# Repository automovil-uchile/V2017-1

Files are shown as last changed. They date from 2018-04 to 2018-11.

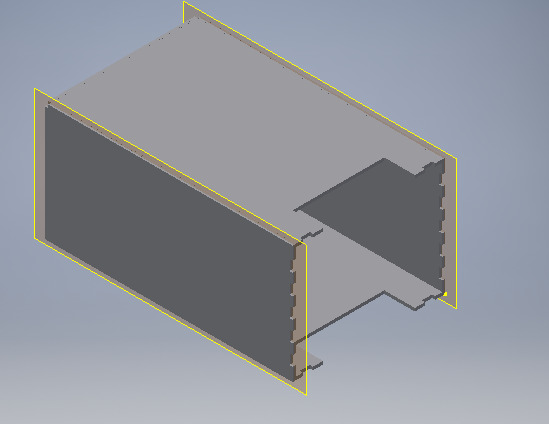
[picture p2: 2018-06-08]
sensor_direccion/caja.jpeg

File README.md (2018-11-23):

# Electromobility

## EL5004 - Taller de Diseño 2018 - Beauchef Proyecta

The following repository holds the documentation of the work done for the course EL5004. The scope of the work is to develop an electric car from the perspective of power electronics, control, communications and hardware.

## How to use this repository?

If all you want is to access the code to make your own electric car control system, please look at the /code folder. Inside it there are the necessary files to make all happen. Follow the instructions in the next url https://www.arduino.cc/en/Guide/Libraries to install correctly the library. The program is mainly written in C++, so you must be in some level familiar with it to modify the codes. The code was tested under the Arduino UNO and DUE boards, but is highly recommended to use the last one, because of the number of I/O connections required. There is a Python early version of the control systems with some kind of signal visualization, developed for the platform Raspberry Pi.

Our first work started at Spring 2017. It was almost bibliography review and design of the main electrical systems. There are auxiliary programs inside folders /spi, /sensor_direccion and /scripts_sensor_dir_simulado. The first one is an adaptation of SPI communication protocol for the board UNO, where it acts as Master and the sensors hardware as Slaves. Folder /sensor_direccion has the code to read the yaw angle sensor and the last folder is a simulation of the output from the yaw sensor to test how the machine reads the information.

Any questions through GitHub only.

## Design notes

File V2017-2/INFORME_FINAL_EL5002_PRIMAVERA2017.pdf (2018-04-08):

Universidad de Chile
Facultad de Ciencias Físicas y Matemáticas Departamento de Ingeniería Eléctrica Introducción al Taller de Diseño EL5002

# Introducción al Taller de Diseño EL5002

# Beauchef Proyecta: Electromovilidad

# Informe Final

Integrantes: | José Cornejo Pedro Correa Matías Gracía Cecilia Ibarra Sebastián Jorquera Marcelo Marín Cristian Ortiz de Zárate Rafael Pérez Ricardo Ramos Mauricio Romero Solange Vivanco Claudio Yáñez
Profesor: | Andrés Caba Miguel Patiño Rodrigo Chi

Fecha de entrega: Domingo 17 de Diciembre Santiago, Chile

Índice de Contenidos | I

# Índice de Contenidos

1. Introducción | 1
2. Objetivos | 1
2.1. Generales | | 1
2.2. Específicos | | 1
3. Organización | 2
3.1. Estructura externa | | 2
3.2. Estructura interna | | 2
4. Habilitación | 3
4.1. Baterías | | 4
4.2. Protecciones | | 4
4.3. Cables | | 5
4.4. Presupuesto y Compras | | 5
5. Segunda Etapa | 6
5.1. Baterías de Litio | | 6
5.2. Battery management system (BMS) | | 6
5.3. Interfaz Humano-Automóvil | | 7
5.4. Computador | | 8
5.5. Sensores | 12
5.6. Presupuesto 2da Etapa | 14
6. Condiciones para Recepción Otoño 2018 | 15
6.1. Espacio para baterías | 15
6.2. Anclaje para protecciones y otros sistemas | 15
6.3. Anclaje para pedal de aceleracion | 15
7. Conclusión | 17

# Lista de Figuras

1. | Diagrama de conexiones | | 3
2. | Primer esquemático de protección | | 4
3. | Componentes finales | | 4
4. | Figura del panel de control sugerido | | 7
5. | Diagrama de bloques del computador | | 8
6. Sensor de Velocidad AS5147 | 12
7. Montaje preliminar de sensor en pcb con imán y adaptación mecánica | 14
8. Dimensiones del pedal de acelerador “KELLY 0-5K THROTTLE PEDAL”. Obtenido de Kelly
Control | 16

# Lista de Tablas

1. | Presupuesto habilitación | | 5
Beauchef Proyecta: Electromovilidad | EL5002 Introducción al Taller de Diseño EL5002

Listings | II
2. | Compras habilitación | | 5
3. | Características BMS para opción 1 | | 6
4. | Características BMS para opción 2 | | 6
5. | Características BMS para opción 3 | | 7
6. | Caracteríscticas Arduino Uno | | 9
7. | Caracteríscticas Arduino Uno | | 9
8. Microcontrolador mbed NXP | 10
9. Características del sensor de velocidad propuesto | 13
10. Presupuesto 2da Etapa | 14

# Listings

1. Introducción | 1

# 1. Introducción

El gran desafío de hoy, en la conformación de equipos es integrar un gran número de personas en un objetivo común. El nivel de especialización en la formación académica y la variedad de experiencias, llevan a que se conformen equipos multidisciplinarios donde cada integrante debe estar consciente de su papel, y el de los demás. Durante el desarrollo de este proyecto se buscó interiorizar y hacer parte, en la medida de lo posible, a todos los involucrados en el trabajo multidisciplinario, integrando equipos de diversas áreas:

Ingeniaría Civil Eléctrica

Ingeniería Civil Mecánica

Diseño Industrial

El trabajo multidisciplinario es clave en el funcionamiento de cualquier equipo, ya que permite la formulación de ideas con distintas perspectivas, además de la entrega soluciones especializadas. El proceso de trabajo multidisciplinario, La implementación para realizar la validación del sistema implementado y Las características definidas para la implementación futura serán el foco de este documento.

# 2. Objetivos

## 2.1. Generales

El objetivo final propuesto es el diseño y la implementación del sistema eléctrico, de un automóvil diseñado y concebido en conjunto entre estas 3 especialidades, en el contexto del ramo Ïntroducción al taller de diseño ² "Taller de diseño". En el semestre actual (Primavera 2017) el equipo se limitó a llevar a cabo la concepción de diseño y prueba de concepto.

## 2.2. Específicos

Para la implementación del sistema eléctrico, se requiere realizar dos etapas distinguibles:

1ra Etapa o Habilitación: Tiene como finalidad probar el diseño planteado y los equipos adquiridos; para de esta forma determinar una correcta implementación final.

2da Etapa o Implementación Final: Culminación del proyecto, incluye el funcionamiento de los sistemas eléctricos ya probados y las pruebas de capacidad real del vehículo.

El proceso de trabajo multidisciplinario, La implementación para realizar la validación del sistema implementado y Las características definidas para la implementación futura serán el foco de este documento.

3. Organización | 2

# 3. Organización

## 3.1. Estructura externa

El proyecto, por definición, se divide en dos secciones:

Base: compuesto por estudiantes de Ingeniería Civil Mecánica. Divida en tres subsecciones.

- Eje Delantero
- Bastidor
- Eje Trasero

Carenados o carrocerías: compuesto por estudiantes de Ingeniería Civil Eléctrica, Ingeniería Civil Mecánica y Diseño Industrial. Al igual que la base, también se divide en tres subsecciones, a las cuales se asignan 4 integrantes de la división eléctrica respectivamente.

## 3.2. Estructura interna

Se divide el diseño eléctrico fundamental y transversal para los 3 carenados y la base, en 2 equipos:

Potencia

Control

Para facilitar la comunicación, se elige a un coordinador para cada equipo; cuya responsabilidad principal es establecer un régimen de comunicación regular con los integrantes de las otras disciplinas de Beauchef Proyecta.

Posterior a esto, se decide democráticamente unificar los grupos y centrar la comunicación en un coordinador común. Este mantiene las mismas responsabilidades del periodo anterior.
Se realiza una reasignación de tareas, esto junto a nuevas divisiones:

Habilitación: Encargados de determinar las conexiones y sistemas necesarios para este primer periodo de pruebas.

Diseño 2da Etapa: Encargados de continuar el estudio de componentes necesarios para la segunda etapa del proyecto.

4. Habilitación | 3

# 4. Habilitación

Para llevar a cabo la habilitación se dispone de dos motores bldc, con sus correspondientes drivers, además de interruptores simples de dos posiciones y un potenciómetro dual. El driver del motor considera varias funcionalidades integradas como un botón de encendido y apagado, sentido, freno y aceleración. Para la implementación se consideraron estas funciones y se conectó el circuito como se muestra en la figura 1.


Figura 1: Diagrama de conexiones

El vehículo está diseñado para ser alimentado mediante baterías de litio, ya que estas proveen una mayor densidad energética que las baterías tradicionales de plomo-ácido, lo cual se traduce en un menor peso, factor crucial para el óptimo funcionamiento de esta aplicación.
Dada la potencia del sistema y la magnitud de las corrientes involucradas por el bajo voltaje de funcionamiento (48[V]), resulta necesario implementar protecciones pertinentes que eviten el daño tanto a los equipos, como al usuario en caso de falla. También se requieren líneas de transmisión apropiadas para energía y señales de control, de modo que las primeras no se sobre calienten y las últimas no perciban interferencia por parte de los campos magnéticos generados por las altas corrientes.

4.1 Baterías | 4

## 4.1. Baterías

Inicialmente se estudiaron 4 bancos de baterías de litio, los cuales fueron descartados por limitaciones espaciales dadas por dimensiones y geometría del bastidor del vehículo. Posterior a esto se plantearon 2 soluciones:

Conseguir paquetes de baterías más pequeños, aumentando así el costo final del proyecto, pero manteniendo los requerimientos originales del auto.

Modificar las especificaciones del vehículo, limitarlo para un solo usuario y reasignar esa masa a baterías de plomo-ácido.

Dado el contexto del vehículo, perteneciendo este a la iniciativa Beauchef Proyecta, se considera pertinente evaluar la primera opción; ya que esta inversión puede significar una solución a problemáticas de futuros proyectos. Es por esto, que se cree que un banco de baterías de litio sería una buena adquisición; de alto valor para Beauchef Proyecta, el Departamento de Ingeniería Civil Eléctrica y la Universidad de Chile.

## 4.2. Protecciones

En la fase inicial de este proyecto se consideran como componentes principales para la protección:

Relé térmico: Dispositivo para las sobrecargas lentas y continuas de corriente.

Fusible: Componente encargado de los corto circuitos. En el caso de motores se usan usualmente lentos.

Contactor: Componente electromecánico usado para el corte o cierre de corriente.

Estos componentes en un comienzo son suficientes para la protección de los dispositivos eléctricos.

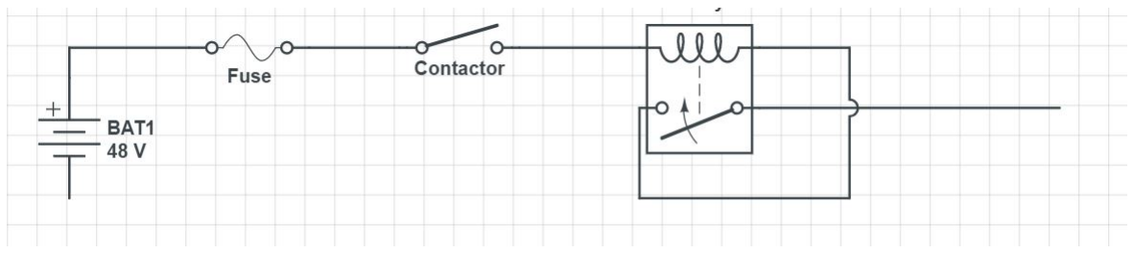
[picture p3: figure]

Figura 2: Primer esquemático de protección

En la figura 2 se puede apreciar la unión de los tres sistemas de seguridad incorporados. Finalmente se decide simplificar el modelo eliminando el relé térmico.

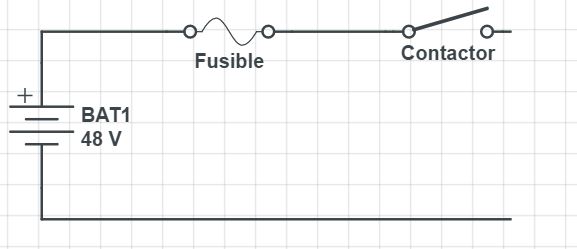
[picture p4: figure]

Figura 3: Componentes finales

En la figura 3 se puede ver los elementos usados para la protección final.

4.3 Cables | 5

## 4.3. Cables

Para la transmisión de potencia, se compraron cables de 2AWG, aproximadamente 6.54mm de diámetro. Por otra parte, para control, se evaluó la posibilidad de comprar cables apantallados; idea que fue desechada en honor del ahorro y buen uso del presupuesto entregado. De esta manera, se compraron cables no apantallados, de tipo 1 par 18AWG.

## 4.4. Presupuesto y Compras

Como se puede apreciar en las siguiente tabla, se realizó un presupuesto preliminar; el cual fue modificado por limitaciones de proveedor.

Tabla 1: Presupuesto habilitación

Compras Presupuestadas | Lugar | Cantidad | Precio [$]
Fusibles | NDU | 10 | 32.840
Portafusibles | NDU | 1 | 38.452
Pulsador | GOBANTES | 2 | 14.510
Cables de control | VITEL | 100[m] | 21.330
Cables de potencia | RHONA | 20[m] | 63.740
Potenciometro | - | 1 | 2.000
Total | | | 172.872

Se realizó un nuevo presupuesto, con nuevos proveedores. Como resultado de las negociaciones con estos, se obtuvieron los siguientes costos.

Tabla 2: Compras habilitación

Compras Realizadas | Lugar | Cantidad | Precio [$]
Fusibles | ZONAINDUSTRIAL | 10 | 34.213
Portafusibles | ZONAINDUSTRIAL | 1 | 31.202
Pulsador | GOBANTES | 1 | 4.055
Cables de control | RHONA | 100[m] | 24.276
Cables de potencia | RHONA | 20[m] | 57.001
Interruptores | - | 6 | 3.000
Potenciometro | - | 1 | 2.000
Total | | | 155.747

5. Segunda Etapa | 6

# 5. Segunda Etapa

## 5.1. Baterías de Litio

Anteriormente se planteó la necesidad de integrar baterías de Litio al sistema, esto para reducir la masa total del vehículo y aumentar la densidad energética del banco de baterías. Luego de un extenso periodo de cotizaciones, se concluye un valor promedio de $145.000 para una batería de 48[v] 10[Ah]. Para alimentar ambos motores en condiciones nominales, por una hora, se requieren un total de 16 baterías; afortunadamente, se puede instalar un banco de baterías que cumpla parcialmente esta demanda, sin afectar su funcionamiento.

## 5.2. Battery management system (BMS)

Para la habilitación se descartó el uso de BMS, ya que se trabajará con baterías de plomo. En el caso de la implementación final, donde se considera el uso de baterías de litio, es muy importante contar con un BMS. Por lo cual se han evaluado múltiples alternativas. A continuación se presentan tres posibles opciones con sus principales características, las cuales cuentan con ciertas características comunes como por ejemplo los 48 [V] que requieren los motores:

Opción 1: Puede ser conectado a 13 celdas; vía UART se puede leer voltaje, corriente, ciclos, temperatura, etc. Cuenta con soporte para bluetooth. La protección viene dada por MOSFET. Las dimensiones que posee es de 172x60x8 mm. El precio de este BMS es de 56 dolares, sin incluir traslado.[1] La siguiente tabla muestra mas detalles:

Voltaje de carga de entrada: 4.25*Numero de baterías Voltaje sobrecarga: 4250 ±50mV Voltaje sobredescarga:2800 ±50mV Corriente sobrecarga: 30 A Corriente de sobredescarga: 180 A PRECIO: [$]35.597

Tabla 3: Características BMS para opción 1

Opción 2: Puede ser conectado a 16 celdas; vía UART se puede leer voltaje, corriente, ciclos, temperatura, etc. Cuenta con soporte para bluetooth. La protección viene dada por MOSFET. Las dimensiones que posee es de 170x60x25 mm. El precio de este BMS es de 59 dolares, sin incluir traslado.[2] La siguiente tabla muestra mas detalles:

Voltaje de carga de entrada: 4.25*Numero de baterías Voltaje sobrecarga: 4250 ±25mV Voltaje sobredescarga:2800 ±50mV Corriente sobrecarga: 30 A Corriente de sobredescarga: 180 A PRECIO: [$]37.503

Tabla 4: Características BMS para opción 2

Opción 3: Puede ser conectado a 5 celdas. La protección viene dada por MOSFET. El precio de este BMS es de 10 dolares, sin incluir traslado. [3] La siguiente tabla muestra mas detalles:

5.3 Interfaz Humano-Automóvil | 7

Voltaje de carga de entrada: 4.25*Numero de baterías Voltaje sobrecarga: 4250 ±25mV Voltaje sobredescarga:2250 ±50mV Corriente sobrecarga: 50 A PRECIO: [$] 6.357

Tabla 5: Características BMS para opción 3

De las tres opciones presentadas la ultima es la menos viable, ya que no se cuentan con especificaciones claras, a pesar de que se solicito mas información al proveedor, este no respondió, además es el único de los modelos presentados que solo acepta baterías de litio (no acepta baterías de LiFePo4)

## 5.3. Interfaz Humano-Automóvil

La interfaz del usuario esta compuesta por los componentes de software y hardware que entregan información y control al usuario. Se espera integrar un panel de control que permita al usuario controlar el vehículo. Las consideraciones del panel de control son las siguientes:

Disponer de botón de on/off

Botón de reversa

Botón de freno

Potenciómetro

Cada uno de los carenados cuenta con diferentes requerimientos para la implementación del panel de control y la forma de visualizar la información, a modo de referencia se muestra en la figura 4 un ejemplo de panel de control sugerido, con las características siguientes:

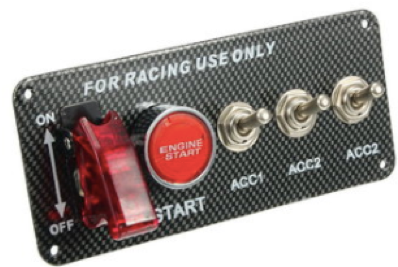
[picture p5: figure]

Figura 4: Figura del panel de control sugerido

Precio: $24.401- Dimensiones: 7 cm * 15 cm * 5 cm.

Material: Metal / plástico de fibra de carbono

Voltaje de funcionamiento: 12 V

Corriente de trabajo: 400 A

Vida Eléctrica: 50000 TIEMPOS

5.4 Computador | 8

Peso del artículo: 0.45 KG

Color: Ver Figura 4

Aplicación: Universal

Fácil de apagar en una emergencia desde cualquier ángulo, incluso con guante, no se apaga de la vibración.

## 5.4. Computador

Se presentará las opciones consideradas para el computador a bordo del automóvil. Todas consideran el uso de bus CAN con protocolo 2.0B para la comunicación entre sensores y computador central, mientras que la información que se pretende dar al usuario será mostrada a través de una pantalla LCD conectada a una Raspberry Pi a través del puerto USB de los microcontroladores. La configuración se observa en el diagrama de bloques de la 5

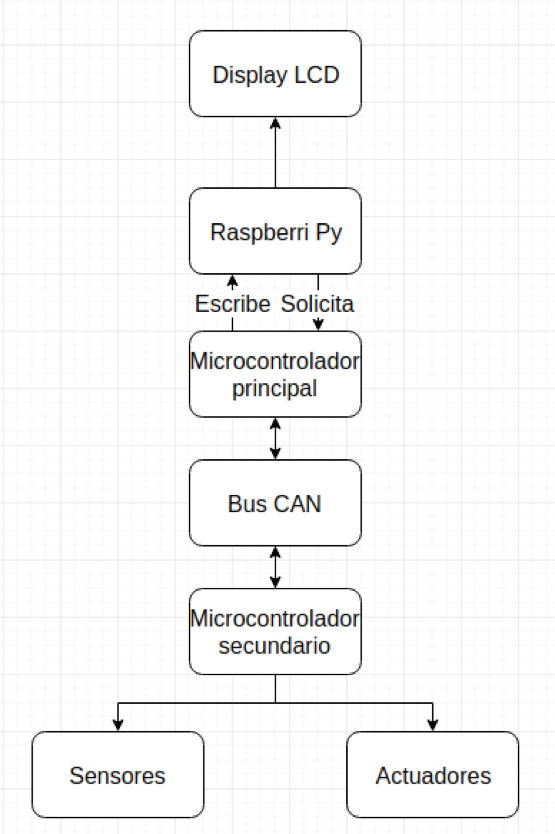
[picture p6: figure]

Figura 5: Diagrama de bloques del computador

Bus CAN: El bus CAN fue creado por Bosch para comunicar distintos microcontroladores en un sistema determinado. Está estandarizado a través de la norma ISO 11898. Existen dos velocidades de transmisión. La primera es la del protocolo ISO 11898-2 cuya tasa es de 1Mbits e ISO 11898-3 con una tasa de 125 kbits. El protocolo CAN considerado en la elección de microcontrolador es el 2.0B. Precios en dólares.

Opción 1: Arduino Uno con CAN bus shield SK Pang electronics, las características de Arduino uno se observan en la tabla 6

5.4 Computador | 9
Microcontroller | ATmega328P
Operating Voltage | 5V
Input Voltage (recommended) | 7-12V
Input Voltage (limit) | 6-20V
Digital I/O Pins | 14 (of which 6 provide PWM output)
PWM Digital I/O Pins | 6
Analog Input /O Pin | 20 mA
DC Current for 3.3V Pin | 50 mA
Flash Memory | 32 KB (ATmega328P) of which 0.5 KB used by bootloader
SRAM | 2 KB (ATmega328P)
EEPROM | 1 KB (ATmega328P)
Clock Speed | 16 MHz
LED_BUILTIN | 13
Length | 68.6 mm
Width | 53.4 mm
Weight | 25 g

Tabla 6: Caracteríscticas Arduino Uno

Las características Can bus shield SK Pang electronics se pueden observar en la Tabla 7

CAN v2.0B at 1 Mb/s
High speed SPI Interface (10 MHz) Standard and extened data and remote frames CAN connection via standard 9-way sub-D connector Power can supply to Arduino by sub-D via fuse and reverse polarity protection. Socket for EM406 GPS module Micro SD card holder
Connector for serial LCD
Reset button
Joystick control
Two LED indicator

Tabla 7: Caracteríscticas Arduino Uno

Dentro de las consideraciones de usar un Arduino Uno como computador central y controlador del bus CAN es que el entorno de programación no permite crear un código optimizado para los diversos cálculos que debe llevar a cabo tanto para estimar las mediciones de los sensores como también para el diferencial. Una posible solución es programar al Arduino directamente en C, tanto los programas a utilizar para cálculos y de control del bus CAN, aumentando la complejidad del punto de vista de la creación de software nuevo.

Precio Bus CAN $ 38.43 [4]
Precio Arduino Uno $ 29.00 [5]

Opción 2: Microcontrolador mbed NXP LPC1768 y transceiver CAN MCP2551.Las características NXP LPC1768 se observan en la tabla 8

5.4 Computador | 10

Tabla 8: Microcontrolador mbed NXP.

ARM Cortex-M3 Core | · Three SSP / SPI controllers
- 100 MHz operation | · Three I2C-bus interfaces with one supporting
| fast mode plus (1-Mbit/s data rates).I2S inter-
| face for digital audio
- Nested vectored interrupt controller for fast deterministic interrupts
- Wakeup interrupt controller allows automatic wake from any priority interrupt | Analog peripherals
- Memory protection unit | · 12-bit ADC with eight channels
- Four reduced-power modes: sleep, deep sleep, power-down and deep power-down | · 10-bit DAC
Memories | Other peripherals
- 512 kB flash memory | · Ultra-low-power (<1uA) RTC
- 64 kB SRAM | · General-purpose DMA controller with eight
| channels
Serial Peripherals | · Up to 70 GPIO
- 10 / 100 Ethernet MAC | · Motor control PWM and quadrature encoder
| Interface to support three-phase motors
- USB 2.0 full-speed device / host / OTG con- troller with on-chip PHY | · Four 32-bit general-purpose timers/counters
- Four UARTs with fractional baud rate genera- tion, RS-48, modem control, and IrDA | Package
- Two CAN 2.0B controllers | · 100-pin LQFP (14 mm x 14 mm x 1.4 mm)

Las características del MCP2551 son:

Supports 1 Mb/s operation

Implements ISO-11898 standard physical layer requirements

Suitable for 12V and 24V systems

Externally-controlled slope for reduced RFI emissions

Permanent dominant detect

Low current standby operation

High noise immunity due to differential bus implementation

El microcontroldor presenta mejores prestaciones que el arduino UNO en cuanto a velocidad del reloj, memoria RAM y FLASH. Además de tener incorporado el protocolo CAN 2.0B y pines dedicados, sin embargo, es necesario utilizar el transceiver nombrado anteriormente. El lenguaje de programación utilizado es C en el microcontrolador. Existe una comunidad de desarrolladores y se encuentra documentada la implementación del bus CAN. Considerar además la construcción de una placa para el transceiver CAN y el microcontrolador.

Precio Microcontrolador $ 84.00 [6]
Precio Microcontrolador $ 52.06 [7]
Precio Transceiver $ 2.00 [8]

Opción 3: XMOS xCORE-200 General Purpose sliceKIT que presenta las características siguientes

5.4 Computador | 11

Supports 1 Mb/s operation

XCORE-200 USB SLICEKIT FEATURES

Flexible core board. 2000MIPS 16-core multicore microcontroller with 512KB SRAM (XU216-512-FB236) Three digital I/O slots for sliceCARDs

High Speed USB Device

Full Speed USB Host

Includes USB A/B sliceCARD, and xTAG debug adaptor

Library components and demos to get you started quickly

Supported by xTIMEcomposer software tools

La tercera opción corresponde a un microprocesador xmos xcore-200 con tres tarjetas de extensión: is-bus (CAN2.0B), Ethernet y USB. Es el microprocesador con más prestaciones de los analizados. Es posible utilizar los distintos núcleos para procesar de forma paralela el diferencial, sensores, CAN, etc. Sin embargo, es necesario comprar otro microcontrolador que sea cpaz de leer sensores y controlar el bus CAN desde el otro lado. En los dos casos anteriores se debe igualmente comprar el controlador para sensores, sin embargo, se puede utilziar el mismo sin mayores problemas. Tanto el micrcontrolador XMOS xCORE 200 como el kit con las tarjetas antes nombradas se encuentra obsoleto y agotado (para Chile, no así si se compra desde UK). Se puede programar en C, C++ y xC.

Precio: $275 [9] Precio: Raspberri Py 3 Model B: $58.00 [10]

Dadas las tres opciones, se piensa que la mejor opción tomando en cuenta el precio, disponibilidad, implementabilidad y complejidad es la número 2, dado que tiene mejores prestaciones que un Arduino Uno, además es posible de programar en C nativamente y tiene documentación extensa en la red. Por otro lado, si es que hay problemas con el paralelismo de los procesos, se puede comprar un microcontrolador extra y utilizar memorias de lectura/escritura entre ambos, de forma que procesos críticos del automóvil se pueden calcular en tiempo real sin bajar el rendimiento en la tasa de transmisión de datos o dejar de lado al diferencial.

5.5 Sensores | 12

## 5.5. Sensores

En lo que sigue se detallan cada uno de los sensores a implementar con sus respectivos usos, ubicación y cotización.

Sensor de Velocidad: Este sensor se ubicará en el eje de rotación del motor con el propósito de medir directamente las revoluciones por segundo y así transformarlo a velocidad lineal del auto. Esto es necesario para que el usuario sepa y tenga noción de la velocidad desarrollada. El sensor cotizado es magnético fabricado por AMS y distribuido por Digi-Key. El sensor se muestra en la figura 6.

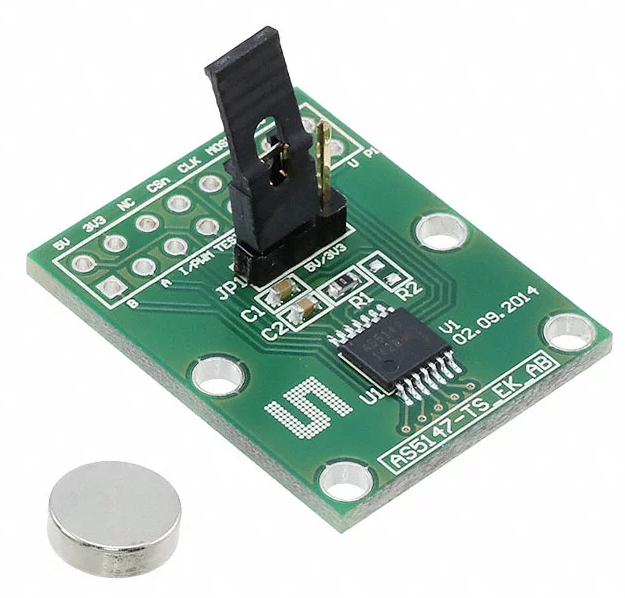
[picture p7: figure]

Figura 6: Sensor de Velocidad AS5147

Este sensor mide la posición y rotación para luego convertirla en velocidad lineal. A continuación se muestra una tabla con sus características. El precio de este dispositivo es de $ 11.820 más el costo de envío.

5.5 Sensores | 13

Tabla 9: Características del sensor de velocidad propuesto

Beneficios | Características
Fácil de usar | Compensación dinámica de error en ángulo DAEC
Buena resolución para el motor y control de posición | Núcleo de 14 bits de resolución
Opción versátil en cuanto a interfaz | Interfaces de salida independientes: SPI, ABI, UVW, PWM
No es necesario un programador | Posición cero, configuración programable
Admite aplicaciones de seguridad desafiantes | Autodiagnóstico
Bajo costo para el sistema | Inmune al campo callejero externo

Sensor de Dirección del volante Éste sensor se localizará en el eje de de rotación del volante y medirá la rotación de éste para poder determinar la diferencia de velocidades necesaria en las ruedas traseras a la hora de virar al manejar. Es importante que el sensor sea capaz de medir la posición absoluta en todo momento, incluso al momento de encender el automóvil, por lo cual la solución escogida consiste en un sensor absoluto de una vuelta adaptado mecánicamente para ser capaz de abarcar el rango completo de rotación del volante, correspondiente a aproximadamente 2,25 vueltas de esquina a esquina. Como el automóvil no se moverá a una velocidad muy elevada, las diferencias de velocidades en las ruedas traseras no serán tan grandes a la hora de virar. Es por ésto que un sensor de 8 bits se considera más que suficiente para el trabajo. Además el sensor debe soportar condiciones de polvo y humedad, por lo cual se escoge un sensor de tipo magnético.

El sensor cotizado corresponde al AS5030, el cual posee salida serial y PWM. En éste caso se utilizará la salida serial para ser convertida y transmitida a través del bus CAN. Para ello será necesario implementar las adaptaciones mencionadas en el la sección 5.3.

La adaptación mecánica de la cantidad de rotación se aplica mediante el uso de engranajes compuestos, de manera que sean capaz de hacer una adaptación de aproximadamente 3:1 sin tener un tamaño radial excesivo como con el uso de engranaje simple. Además de ésto existirá un rango de holgura en los extremos de rotación de manera que se evite que el sensor pueda pasar de marcar 360◦ a 0◦ o viceversa accidentalmente. Éste movimiento estará limitado por las restricciones de rotación impuestas en el eje, por lo cual resulta imposible que el sensor sea roto por aplicación de fuerza excesiva.
Ésta adaptación pretende ser fabricada en plástico mediante impresoras 3D disponibles en varios lugares de la facultad.

El montaje se realiza de manera radial, en donde el eje es pasado a través de la estructura del sensor, el cual posee un agujero central donde se ubica el engranaje primario. La salida en forma de cables del sensor se realiza por la parte superior de modo que al interior de la estructura estará la electrónica donde se mide y transforma la señal a CAN. Éstos cables son finalmente conectados al bus CAN.

5.6 Presupuesto 2da Etapa | 14

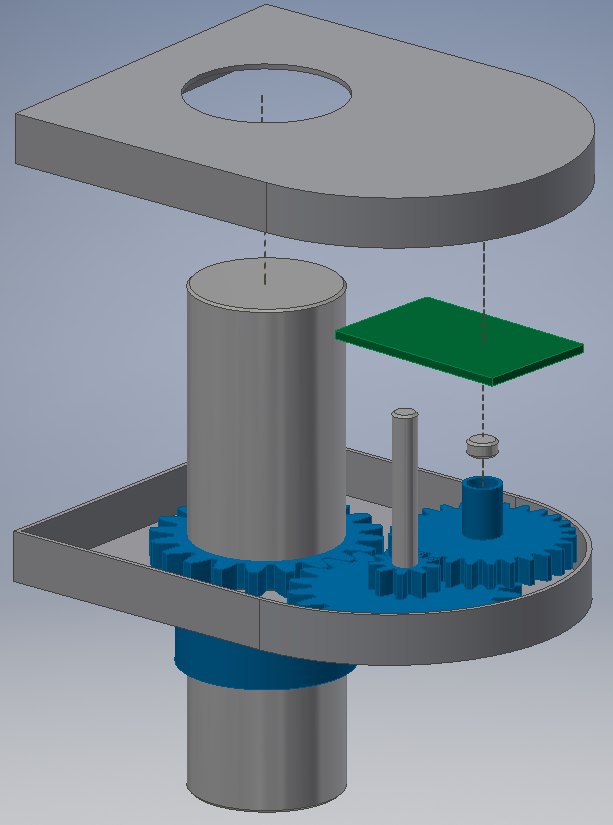
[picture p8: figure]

Figura 7: Montaje preliminar de sensor en pcb con imán y adaptación mecánica

## 5.6. Presupuesto 2da Etapa

En la siguiente tabla, se presenta el presupuesto de las piezas fundamentales para llevar a cabo la próxima etapa del proyecto. Es necesario mencionar, que solo se considerará un BMS dentro de este presupuesto siempre y cuando se utilice un banco de baterías de litio, las cuales tampoco han sido consideradas en esta tabla.

Tabla 10: Presupuesto 2da Etapa

Compras Presupuestadas | opción 1 [$] | opción 2 [$] | opción 3 [$]
Pedal Acelerador | 40.000 | 40.000 | 40.000
Botonera | 27.877 | 27.877 | 27.877
Computador | 42.886 | 87.807 | 211.788
Sensor de Velocidad | 11.820 | 11.820 | 11.820
Sensor de Dirección | 9,025 | 9,025 | 9,025
Total | 131.608 | 176.529 | 300.510

6. Condiciones para Recepción Otoño 2018 | 15

# 6. Condiciones para Recepción Otoño 2018

Para pasar a la segunda etapa es necesario corroborar que las condiciones propuestas a las otras disciplinas han sido cumplidas correctamente. A continuación, se presenta una pauta general mediante la cual se revisará lo estipulado durante el primer periodo.

## 6.1. Espacio para baterías

El equipo de Bastidor se compromete a entregar un compartimiento para las baterías, cuyas dimensiones son 1112mm x 289mm x 120mm. Este debe ser retirable en caso de emergencia, además de soportar un peso mínimo del orden de 40kg.

## 6.2. Anclaje para protecciones y otros sistemas

Durante una visita al taller mecánico se llegó a un acuerdo sobre las posiciones de las platinas para los drivers, protecciones y computador del automóvil. La platina correspondiente al computador fue puesta en la zona delantera, donde antiguamente existía un espacio para baterías. La platina delantera además de tener el computador tendrá las conexiones necesarias para operar la comunicación entre dispositivos.

## 6.3. Anclaje para pedal de aceleracion

Se envió al equipo mecánico el plano de la Figura 8, para que se coloque junto al pedal de freno una placa que permita instalar el acelerador.

6.3 Anclaje para pedal de aceleracion | 16

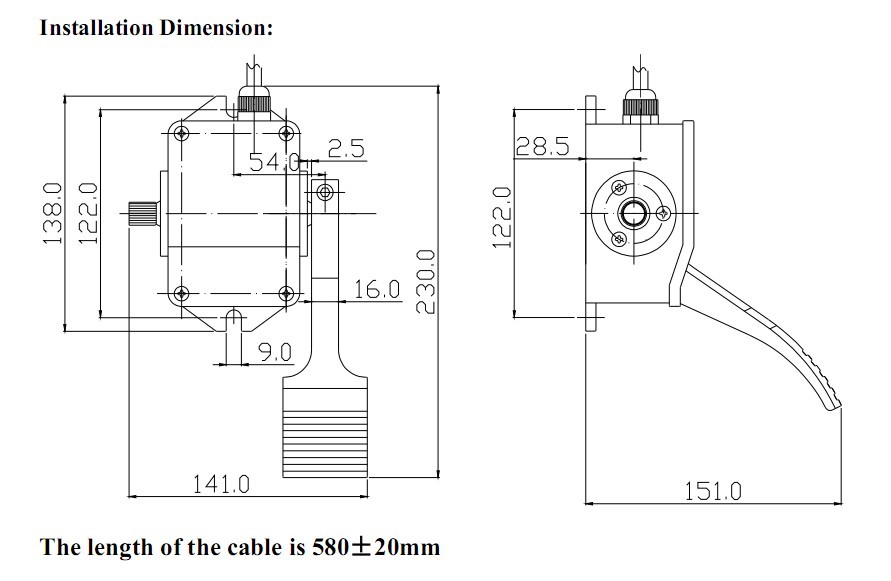
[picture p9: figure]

Figura 8: Dimensiones del pedal de acelerador “KELLY 0-5K THROTTLE PEDAL”. Obtenido de Kelly Control.

7. Conclusión | 17

# 7. Conclusión

La ejecución de un trabajo multidisciplinario conlleva una carga mayor de la esperada si no se trabaja de manera ordenada, pero pueden obtenerse excelentes resultados si se aprovechan las características distintivas de cada uno de sus integrantes. Dentro de los mayores desafíos que se vivieron durante el desarrollo del proyecto fue no fijar claramente las funciones que cada uno debía desarrollar, así como los tiempos esperados para que ello ocurriera. También, al tener cada uno diferentes horarios resultaba difícil coordinar. Durante el desarrollo del proyecto fue posible ir adaptando el trabajo a las habilidades de cada uno, para facilitar el compromiso y cumplimiento de cada uno de los desafíos del proyecto. Además, fue necesario disponer de una parte importante del tiempo de desarrollo en definir las áreas de acción, y se realizaron constantes modificaciones en las metodologías de trabajo para apuntar al cumplimiento del objetivo. Finalmente se logro el trabajo en conjunto.

En cuanto a la habilitación, es necesario mencionar que esta solo comprende el funcionamiento del sistema nervioso del vehículo. No incluye pruebas con carga, ni movilidad alguna.

En relación a las próximas etapas del proyecto, se especificaron las condiciones para la futura implementación. Es necesario mencionar que algunas de las partes pueden variar dependiendo de las especificaciones de carenado. De todas formas, se trató de encontrar la mayor cantidad de elementos transversales para los tres, por ejemplo el panel de cada interior, el cual se implementó de manera similar para encontrar la mayor cantidad de puntos comunes en el funcionamiento del automóvil.

Referencias | 18

# Referencias

[1] [Online]. | Available: | https://www.alibaba.com/product-detail/13S-50A-48V-BMS-PCBA-PCM_
60446882651.html?spm=a2700.7724838.2017115.145.64a918d3kCLS2X (https://www.alibaba.com/product-detail/13S-50A-48V-BMS-PCBA-PCM_60446882651.html)
[2] [Online]. Available: https://www.alibaba.com/product-detail/High-quality-rechargeable-CAN-BUS-bluetooth_60665141291.html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 (https://www.alibaba.com/product-detail/High-quality-rechargeable-CAN-BUS-bluetooth_60665141291.html)
[3] [Online]. | Available: | https://www.alibaba.com/product-detail/Large-supply-lifepo4-48v-15s-18s_
60642011165.html?spm=a2700.7724838.2017115.137.64a918d3kCLS2X (https://www.alibaba.com/product-detail/Large-supply-lifepo4-48v-15s-18s_60642011165.html)
[4] [Online]. Available: http://skpang.co.uk/catalog/arduino-canbus-shield-with-usd-card-holder-p-706.html
[5] [Online]. Available: http://www.mcielectronics.cl/en_US/shop/product/arduino-uno-r3-10230
[6] [Online]. Available: http://cl.rsdelivers.com/product/mbed/mbed-lpc1768/arm-mbed-lpc1768-module/7039238.aspx (http://cl.rsdelivers.com/product/mbed/mbed-lpc1768/arm-mbed-lpc1768-module/7039238.aspx)
[7] [Online]. | Available: | https://www.digikey.com/product-detail/en/nxp-usa-inc/OM11043,598/
568-4916-ND/2138502 (https://www.digikey.com/product-detail/en/nxp-usa-inc/OM11043,598/568-4916-ND/2138502)
[8] [Online]. | Available: | http://cl.rsdelivers.com/product/microchip/mcp2551-i-p/
microchip-mcp2551-i-p-can-transceiver-1mbit-s-1-channel-iso-11898-8-pin-pdip/0402920.aspx (http://cl.rsdelivers.com/product/microchip/mcp2551-i-p/microchip-mcp2551-i-p-can-transceiver-1mbit-s-1-channel-iso-11898-8-pin-pdip/0402920.aspx)
[9] [Online]. Available: https://www.digikey.co.uk/products/en?mpart=XK-SK-X200-ST&v=880
[10] [Online]. Available: http://www.mcielectronics.cl/en_US/shop/product/raspberry-pi-3-model-b-19766

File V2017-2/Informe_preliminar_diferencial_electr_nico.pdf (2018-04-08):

# Reporte Sensor de Dirección

Ricardo Ramos

Beauchef Proyecta

30 de Octubre de 2017

## 1. Preliminar

1.1. ¿Por qué necesitar un Sensor de Dirección?

En un automóvil común y corriente, el sensor de dirección se utiliza para realizar control de estabilidad, es decir, corregir condiciones como sobregiro(oversteering) y subgiro(understeering) al doblar bruscamente ante alguna situación de peligro.

En el caso de el proyecto del automóvil eléctrico no se implementará control de estabilidad debido a las bajas velocidades a las que se moverá. Sin embargo, se utilizará para realizar el diferencial electrónico.

Un diferencial permite que, al doblar, las ruedas puedan girar a distintas velocidades/torques para evitar que la rueda exterior resbale.

1.2. ¿Cómo realizar el diferencial electrónico?

En primer lugar es necesario saber el ángulo de rotación de las ruedas, ésto determinará qué tan rápido está doblando el automóvil y por ende cuán distintas serán las velocidades relativas entre las ruedas. Existen diversos métodos para calcular la velocidad de las ruedas siendo el más clásico, simple y el elegido, ´ el método del Diferencial de Ackerman.
(Ver Anexo)

### 1.3. Definición del problema

El sensor ser capaz de reconocer con resolución suficiente la rotación de las ruedas.

El sensor debe ser capaz de ser colocado en el eje del volante, ya sea al principio o al final. Los lugares comunes donde se coloca éste tipo de sensores es debajo del volante, antes de la columna, después de la columna, antes de la junta universal o bien antes del piñón en el sistema de piñón y cremallera de la dirección (Al final de todo). Ver figura 2.

El eje del volante es de 30mm de diámetro basado en lo que indican los datos de cubicación de eje delantero.

El eje y las ruedas poseen una razón de reducción en la cual una vuelta y un poco más se traduce en aproximadamente 40 grados de rotación de las ruedas respecto a su orientación regular. Esto quiere ´ decir que aproximadamente 2,5 vueltas totales del volante (de esquina a esquina) se traduce en 80 de rotación de 80 grados de las ruedas. Esta aproximación fue informada hace semanas y no he podido ´ reunirme nuevamente con eje delantero para saber con exactitud cuánto es.

Como los pines del Raspberry Pi 3 son limtados, es probable que sea más conveniente utilizar un sensor que posea comunicación serial. El protocolo más usado por automóviles comerciales es CAN (Controller

Beauchef Proyecta | Sensor de Dirección

Area Network). El equipo nunca se decidió de si utilizaríamos CAN o no así que fue descartado. Una opción simple sería utilizar simplemente SPI.

## 2. Trabajo

Opción 1: Compra de un sensor comercial

En primer lugar se probó buscando sensores de dirección utilizados comercialmente en la industria automovilística. Esta solución es en teoría la más ideal pues sólo basta con comprar el sensor. Sin embargo, ´ presentó problemas: En primer lugar, todos los sensores de éste tipo son manufacturados a pedido por las compañías automotoras, normalmente para modelos específicos de algún automóvil, por lo cual normalmente se encuentra como ’Sensor para X automóvil’ y nunca poseen ninguna especificación de dimensiones o tipo de señal de salida (la cual lo más probable es que sea CAN), etc. Este tipo de sensor se convierte, por lo ´ tanto, en una opción arriesgada al no presentar información. Los escenarios posibles son que no sirva, o que haya que hacerle modificaciones que sólo podrán saberse una vez comprado el sensor. Esta opción ha sido ´ casi descartada por completo.

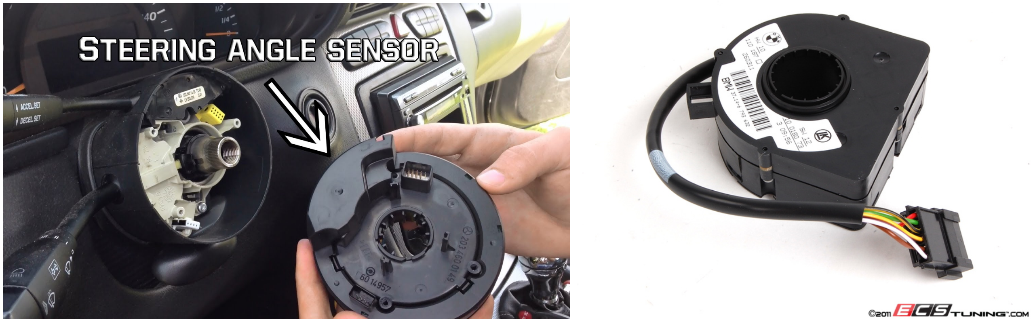
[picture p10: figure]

Figura 1: Sensores Comerciales

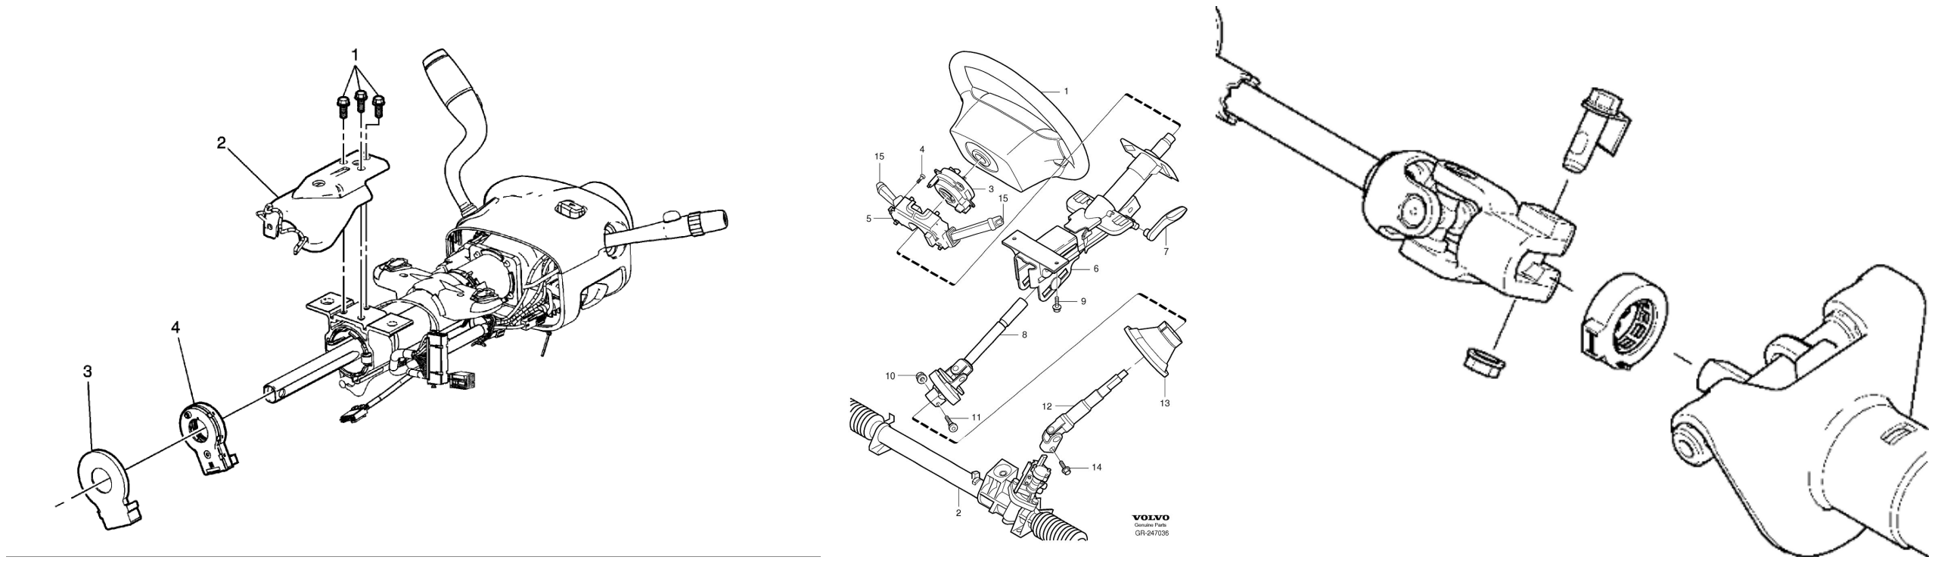
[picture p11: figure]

(a) Debajo de Columna | (b) Debajo de Volan- te
(c) Antes de la Junta Universal

Figura 2: Posicionamiento Sensores Comerciales

Opción 2: Encoder Absoluto Multivuelta

Luego se probó utilizando encoders. Un encoder es un dispositivo que permite saber la rotación de un eje. Se dividen en varias categorías:

Según su tipo de medición: Pueden ser Incrementales o Absolutos.
Un encoder incremental sólo registrará los cambios en la rotación mientras que un encoder absoluto registrará la rotación absoluta respecto a una posición definida.
Dentro de los encoders absolutos existen también los de una vuelta y multivuelta. Un encoder de una vuelta sólo podrá registrar 360 grados mientras que uno multivuelta puede registrar hasta 3 o 4 vueltas.

Según su tipo de tecnología: Pueden ser Magnéticos, Opticos, etc. ´

Sgún su tipo de Acople: Pueden ser con eje o sin eje. Entre los sin eje se encuentran aquellos que son huecos, que atraviesan un eje o bien pueden ser con fondo cubierto, es decir son puestos al final del eje.

A partir de las definiciones anteriores podemos ver que un encoder incremental no es adecuado para la implementación que se desea pues lo que se desea es que la posición del eje sea registrada apenas sea encendido el automóvil, lo cual el encoder incremental no puede hacer.

Un encoder absoluto de una vuelta presenta problemas similares: al ser el eje capaz de dar más de una vuelta al rotar el volante, no se registrará en cual vuelta se estará a la hora de encender el automóvil (la detección del cambio de vuelta puede detectarse estando encendido el automóvil).

Un encoder absoluto multivuelta parece ser la mejor opción. Sin embargo éste tipo de encoders es difícil de encontrar y aquellos que existen suelen ser bastante caros.

A nivel general, los encoders absolutos suelen ser utilizados en la industria por lo cual es fácil encontrarlos para aplicaciones industriales. Esto hace además que tengan datasheets con todas las especificaciones y ´ dimensiones. La desventaja de éstos encoders industriales es que suelen utilizar protocolos más desconocidos o menos usados como SSIo BiSS. Además los precios no están indicados en los sitios web de venta si no que sólo se puede cotizar mediante consulta.

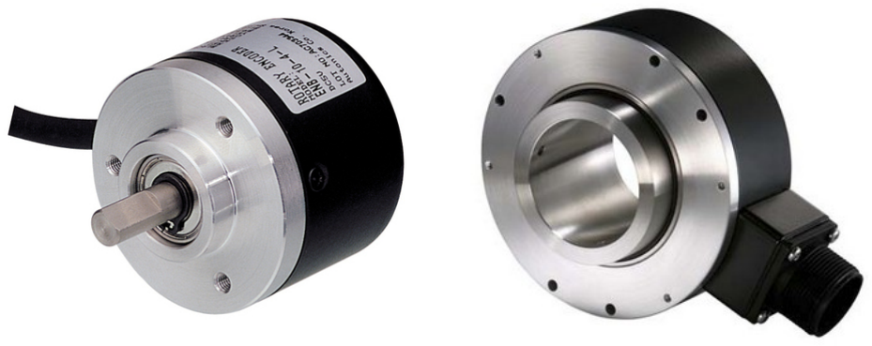
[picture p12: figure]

Figura 3: Encoders Industriales Con eje y Sin eje.

Aquellos que no son industriales normalmente no están diseñados para trabajar con ejes tan grandes como 30mm.
La opción de encoder multivuelta fue descartada.

Opción 3: Encoder Absoluto de una vuelta + manufactura de adaptación inteligente

Esta opción es de las más recientes. En primer lugar se observó a partir de algunas imágenes cómo ´ funcionaban los sensores de dirección comerciales:

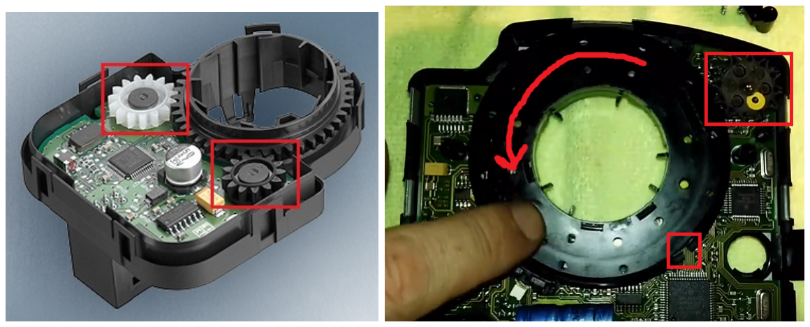
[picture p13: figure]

Figura 4: Sensores Comerciales

En el sensor de la izquierda, se puede observar que el engranaje por donde pasa el eje está acoplado a dos engranajes pequeños. La teoría es que éstos dos engranajes pequeños son encoders absolutos de 1 vuelta. Sin embargo se puede observar que los engranajes poseen número primo de dientes, por lo cual las rotaciones no serán iguales por muchas vueltas. Es decir, en cada vuelta los dos encoders registrarán posiciones distintas, por lo cual es posible reconcer durante muchas vueltas en qué posición se encuentra el engranaje principal.

El sensor de la derecha posee un encoder absoluto óptico en el centro, sin embargo, en la esquina superior derecha se puede observar un engranaje que cuenta la cantidad de vueltas hasta 6 vueltas. En cada rotación del sensor principal, la dentadura en el exterior del anillo gira en 1/6 de vuelta el engranaje contador de vueltas.
Estas parecen ser buenas soluciones. Sin embargo pueden resultar ser más difíciles en la práctica. Por ´ ejemplo, en el caso de la izquierda la cantidad de dientes no se traduce exactamente en la resolución del encoder, por lo cual no estoy seguro de si efectivamente habrían números primos a la hora de ver los niveles de los encoders.

Por otro lado, ambos sensores requieren de no uno si no dos encoders absolutos.
Esta es una alternativa aún en discusión. ´

Opción 4: Encoder Absoluto de una vuelta con eje + manufactura de reducción

Una última opción y que se encuentra en desarrollo. La idea de ésta opción es pensar en una solución simple de implementar tanto mecánicamente como eléctricamente.

Esta solución se basa en implementar simplemente una reducción mediante engranajes del eje principal ´ al encoder, de manera que las multivueltas del eje sean transformadas en una sola vuelta del encoder. En éste caso la implementación de engranajes simples resulta en una engranaje de aproximadamente 3 veces el tamaño del eje, por lo cual resulta en un sensor de gran tamaño. Para evitar ésto se implementa un sistema triple con engranaje compuesto.

Además se ha calculado cuánto realmente se necesita de resolución en el encoder y se ha llegado a que una resolución de 128 niveles (2.8 grados), la resolución de posición en las ruedas es de aproximadamente 0.63 grados, lo cual se considera ser más que suficiente para calcular el diferencial. Además esa es la resolución mínima que se ha encontrado en los encoder, los cuales normalmente son de 1024 niveles. (Ver Anexo)

El encoder de 128 niveles fue encontrado en RSComponentes pero posee salida de bits en paralelo, por lo cual se pretende usar un shift-register o similar para transformar la información de paralelo a serial y poder utilizar SPI.
La reducción fue modelada en Autodesk Inventor y tanto los engranajes como el contenedor pretenden ser impresos en 3D mediante las impresoras del FabLab.

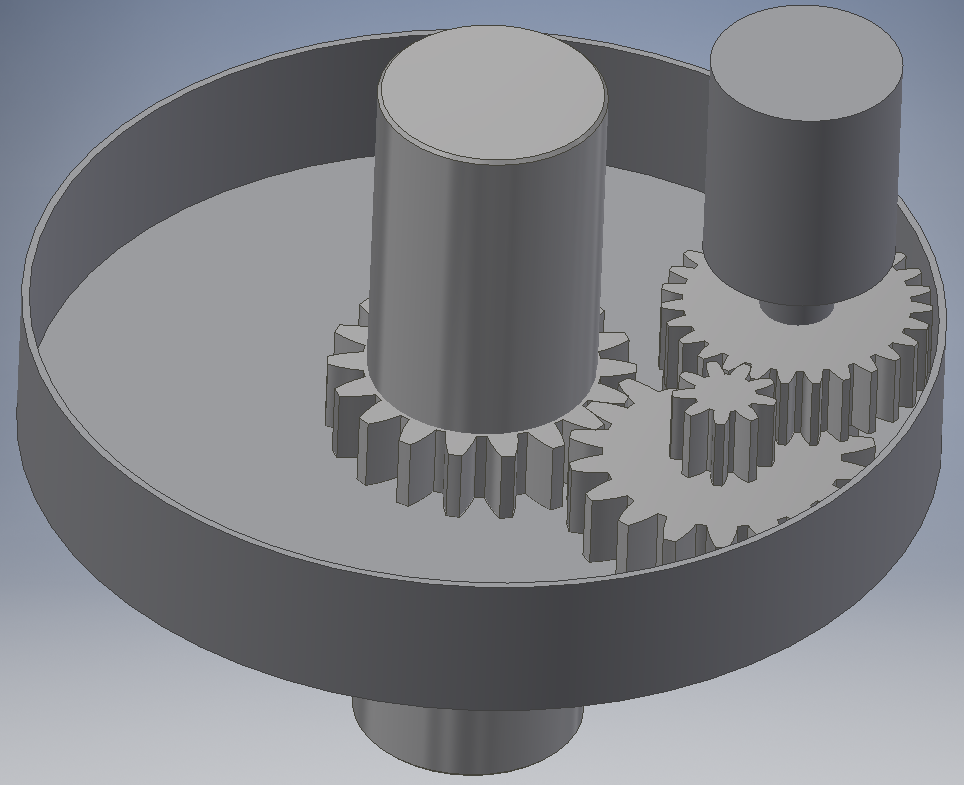
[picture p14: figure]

Figura 5: Preliminar de Sensor a manufacturar. Al centro el eje de la dirección y a la derecha el encoder montado. Vista Abierta.

## 3. Anexo

### 3.1. Diferencial de Ackerman

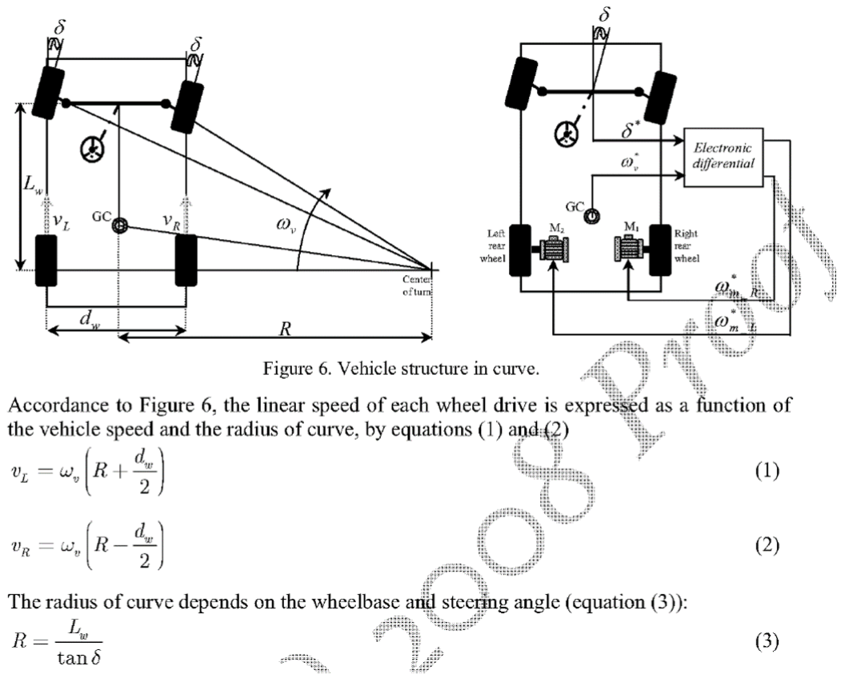
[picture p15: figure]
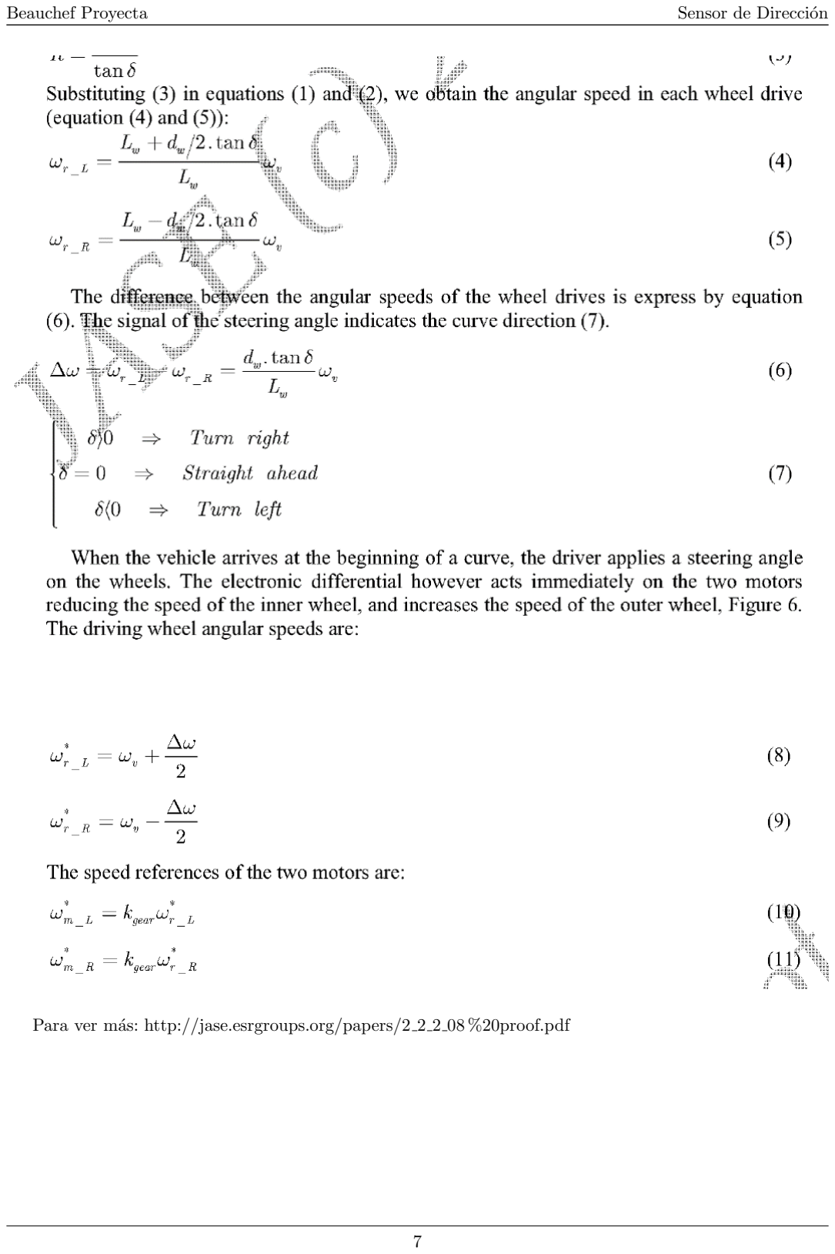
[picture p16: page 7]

Para ver más: http://jase.esrgroups.org/papers/2 2 2 08 %20proof.pdf

### 3.2. Cálculo de Engranajes

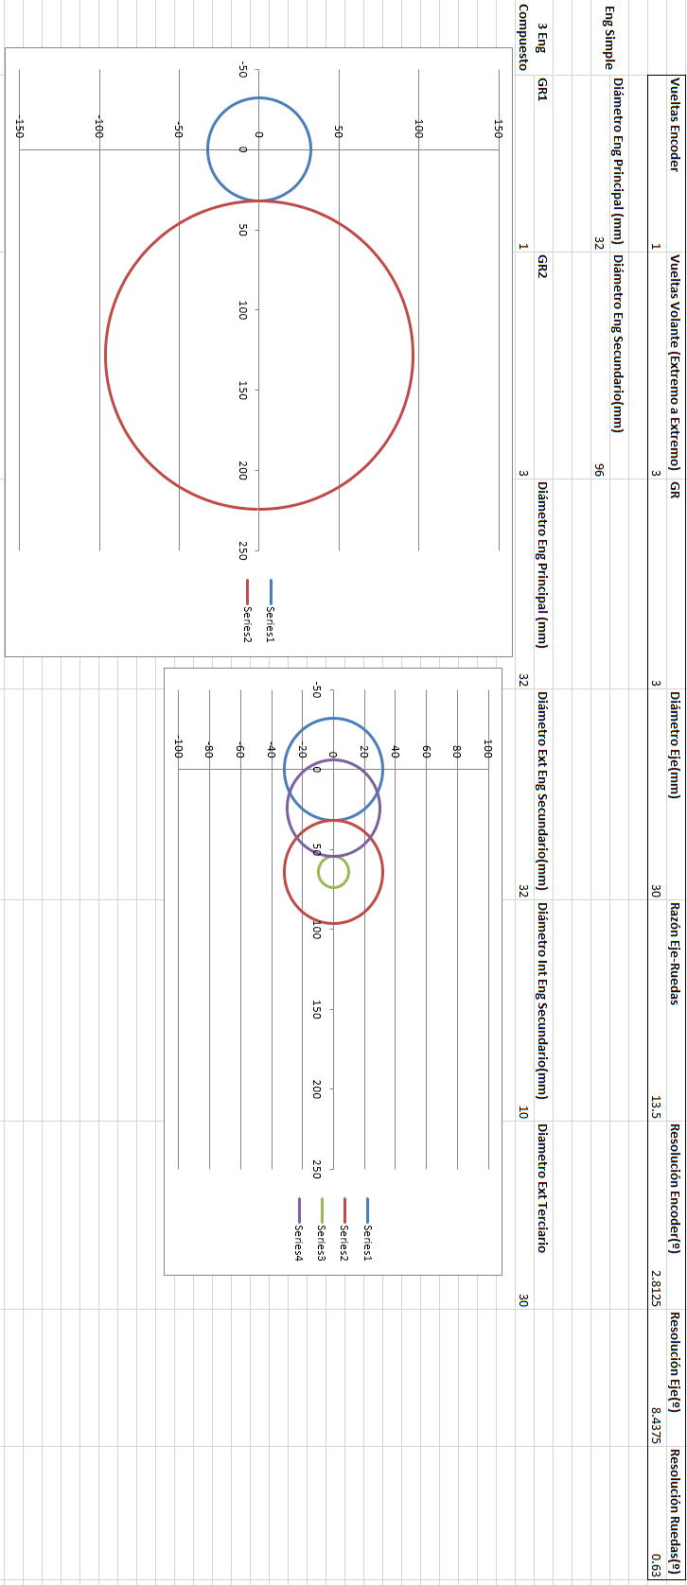
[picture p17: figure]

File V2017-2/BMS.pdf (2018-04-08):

### BMS

Posibles BMS a utilizar:

1. Precio: US: $10 Viene con “datasheet”
13S 50A 48V BMS /PCBA/PCM Protection Circuit Control Board for Li-ion and LifePo4 battery Pack
https://www.alibaba.com/product-detail/13S-50A-48V-BMS-PCBA-PCM_60446882651.html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 (https://www.alibaba.com/product-detail/13S-50A-48V-BMS-PCBA-PCM_60446882651.html)
2. Precio: US:$0.1
Large supply lifepo4 48v 15s 18s lipo bms 10s 60a https://www.alibaba.com/product-detail/Large-supply-lifepo4-48v-15s-18s_60642011165.html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. (https://www.alibaba.com/product-detail/Large-supply-lifepo4-48v-15s-18s_60642011165.html)
3. Precio: US:$59
CAN BUS bluetooth bms 48v 60a https://www.alibaba.com/product-detail/CAN-BUS-bluetooth-bms-48v-60a_60665141291.html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

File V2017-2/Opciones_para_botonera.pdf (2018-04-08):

DEPARTAMENTO DE INGENIERÍA ELÉCTRICA FACULTAD DE CIENCIAS FÍSICAS Y MATEMÁTICAS UNIVERSIDAD DE CHILE
EL5002 – INTRODUCCIÓN AL TALLER DE DISEÑO

# 1 Encendido

## 1.1 Feniex Industries C-1060 Haleo 600 6paneles de Interruptor

Tiempo de envio: 10 días hábiles
Precio: $26.990
CARACTERÍSTICAS
- Un panel de 6 conmutadores
- Interruptores retroiluminados
- Dimensiones: 4 "L x 2.25" W 1.5 "H
- Marco de aluminio ligero y duradero
- Opción entre interruptores de balancín momentáneos negros o interruptores rojos de encendido / apagado
- Marca: Feniex Industries
- Modelo: C-1060

## 1.2 Flip-up Comience Interruptor de Encendido Botón de panel DIY

Modificación del Coche Interruptor accesorio.

Tiempo de envío: 7-20 días hábiles
Precio: $21.694
CARACTERÍSTICAS:
- El peso ligero, rigidez y bien parecido.
- La luz LED de indicación.
- Material: plástico, metal
- Tipo: 12V / 20A
- Dimensiones: Approx.19.2 * 6,2 cm
- Tamaño del paquete: Approx. 23.2 * 19 * 12.5cm
- Peso del paquete: Approx.469g
- Incluye un panel del interruptor de encendido y un set de accesorios de montaje

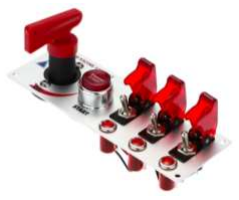
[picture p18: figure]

## 1.3 Iniciar carreras combinación coche interruptor de encendido de panel un botón LED par 12v xh-3018

Tiempo de envío: 7-35 días laborales
Precio: $24.401
CARACTERÍSTICAS
- Dimensiones: 7 cm * 15 cm * 5 cm.
- Material: Metal / plástico de fibra de carbono
- Voltaje de funcionamiento: 12 V
- Corriente de trabajo: 400 A
- Vida Eléctrica: 50000 TIEMPOS
- Peso del artículo: 0.45 KG
- Color: Como la imagen
- Aplicación: Universal
- Fácil de apagar en una emergencia desde cualquier ángulo, incluso con guante, no se apaga de la vibración.
- Incluye: un interruptor de X Sarter, un Relé X y Tornillos De Alambre

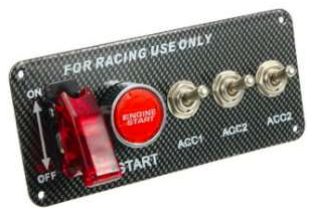
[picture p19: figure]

## 1.4 Interruptor Racing Corte rápido

Tiempo de envío: no supera las 72 horas Precio: $3.500 c/u

CARACTERÍSTICAS
- Permite desconectar rápidamente circuitos.
- Disponible en colores de led: Blanco/Rojo/Azul.
- Voltaje 12V
- Amperaje 10A

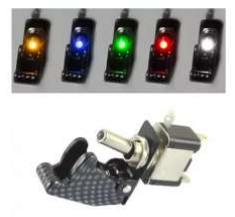
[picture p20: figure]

## 1.5 10 PCS Azúl Led Interruptor Para automóvil

Tiempo de envío: a convenir con la tienda (Las Condes) , 15 días hábiles.
Precio: $61.990
CARACTERÍSTICAS
- 10pcs azul LED interruptor para automóvil/camión encendido 14mm para el agujero del tornillo U.S.
- Condición: 100% nuevo
- Peso: 37 g
- Cambiar estilo de actuación: eje de balancín
- Rating: 20A 12V DC (de 9V ~12VDC)
- Temperatura de funcionamiento: -25 ° C ~ + 85 ° C
- Vida eléctrica: 10000 ciclos
- Especificación: Color: Negro + plata
- Luz "STYLE6 STYLE13"
- Incluye 10pcs interruptor de LED azul 14mm para el orificio del tornillo

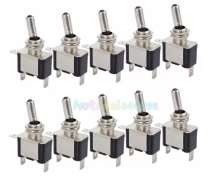
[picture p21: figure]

## 1.6 Interruptor de 12V Interruptor de encendido Motor Relés Int

Tiempo de envío: a convenir con la tienda (Macúl) , 5 a 12 días
Precio: $43.100
CARACTERÍSTICAS
- Tensión de la tarifa 12V
- Material Plástico de aluminio
- Funciona en un vehículo que necesita una fuente de 12 voltios conmutada
- Los interruptores se pueden apagar simplemente cerrando la tapa
- Peso del producto 0.246 Kg
- Tamaño del producto (L x P x H) 9,5 x 7,0 x 6,5 cm
- Color de la luz del LED Colores claros azules
- Corriente 20A
- Voltaje DC 12V
- Incluye Panel de Interruptores Toggle Switch, nueve cables de conexión (35 cm) y cuatro tornillos

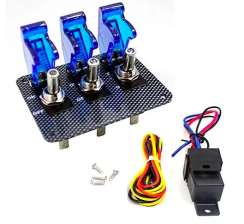
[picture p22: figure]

## 1.7 10pcs Azul Led Interruptor Spst 12v 20a On/Off

Tiempo de envío: a convenir con la tienda (Las Condes) , 15 días hábiles.
Precio: $22.990
CARACTERÍSTICAS
- 10pcs azul luz LED interruptor SPST 12V 20A On/Off para automóvil/coche/barco
- Operating Temperature: -25°C~+85°C

- Electrical Life: 10000 Cycles
- Peso: 37 g
- Cambiar estilo de actuación: eje de balancín
- Valorar:20A 12V DC (de 9V ~ 12VDC)
- Especificaciones:Color: Negro + plataLuz "3"
- Rating: 20A 12V DC
- Resistencia de contacto: 50M?
máximo.R: de aislamiento 500 v DC 100M minFuerza dieléctrica: 1 minuto 1500V ACON/OFF construido en led14mm para el orificio del tornilloConsejos de aplicación:

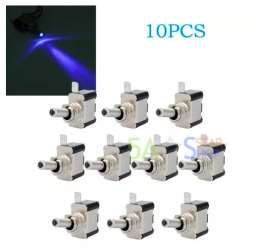
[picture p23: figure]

## 1.8 Interruptor On-Off con tapa y luz para auto

Tiempo de envío: a convenir con la tienda
Precio: $3.990
CARACTERÍSTICAS
- Interruptor de encendido y apagado diseño deportivo luz led incorporada para indicar posición "on" o encendido
- Entregas en nuestra tienda ubicada en Calle Roberto Espinoza, Santiago centro. Metro mas cercano Toesca.
- Horario: Lunes a Viernes de 10 a 20hrs

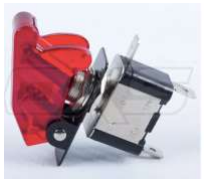
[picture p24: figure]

## 1.9 Repuesto interruptor para vehículo bipolar On-Off Palanca

Tiempo de envío: de 5 a 15 días hábiles
Precio: $19.811
CARACTERÍSTICAS
- Bipolar On-Off palanca metal dc 12v 20ª
- Estructura anti terminales de tornillo óxido sólido y compacto de cableado conveniente.

## 1.10 Repuesto Interruptor Para Vehiculo Automatico 3 Pin Barco

Tiempo de envío: A convenir con la tienda, de 5 a 15 días hábiles
Precio: $15.751
CARACTERÍSTICAS
Tamaño del producto: 1,5 x 2,1 x 2,8

## 1.11 Support 12v 20a Amp Interruptor de palanca

Tiempo de envío: A convenir con la tienda, 10 días hábiles
Precio: $24.990
CARACTERÍSTICAS
- E Support ™ 12V 20A AMP Interruptor de palanca intermitente de luz LED azul SPST ON / OFF Motor de coche Pack de 10
- Condición: A estrenar Entrada: 12V
- Estilo de accionamiento del interruptor: Rocker
- Interruptor SPST 3Pin
- Luz: LED azul

- 12mm para el orificio de tornillo
- Marca: E Support
- Color: Blue LED
- Modelo: CXCP00A10
- Todos nuestros productos tienen boleta o factura (3 meses de garantía).

## 1.12 Mictuning 12v / 24v Aluminio Panel De Interruptor Impermeab

Tiempo de envío: de 15 a 25 días hábiles
Precio: $49.990
CARACTERÍSTICAS
- Incluido 6 on-off 5pin azul LED interruptor de rocker, toma de cigarrillos de 12V, 2.1A / 5V y 1A / 5V cargador de usb dual y voltímetro digital.
- Placa de aluminio, a prueba de rasguño y resistente a la corrosión, con la tapa sellada de goma para todos los zócalos, resistente al agua, a prueba de polvo y a prueba de escombros.
- Potencia de salida máxima de 240W, incorporada Protección de sobrecarga.
- Tamaño compacto de 7 "x4.5" x2.4 "

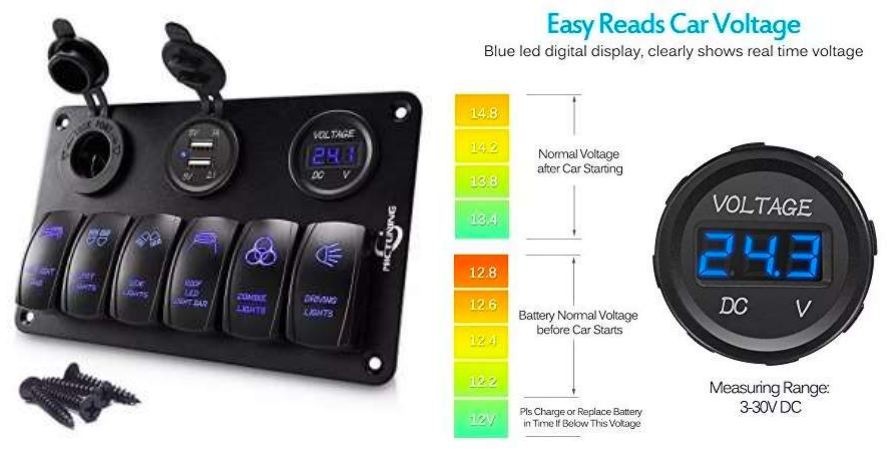
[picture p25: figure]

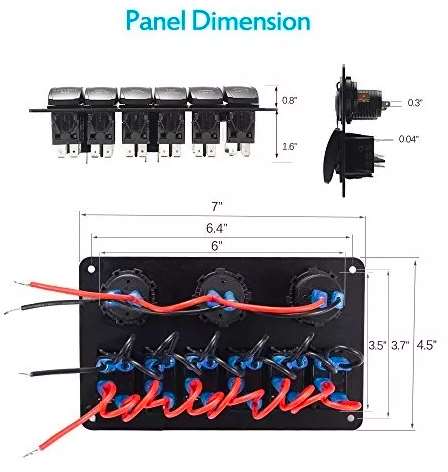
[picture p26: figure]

## 1.13 Interruptor De Encendido Kdl Panel Dc12v Led Fibra De Carbo

Tiempo de envío: de 5 a 12 días hábiles
Precio: $51.200
CARACTERÍSTICAS
- Universal para 12V Power Speediness amp
- Material Aleación de aluminio y plástico.
- Botón de encendido del motor rojo iluminado.
- No se apaga de la vibración.
- Tamaño 15 x 6.5 cm.


## 1.14 Interruptor básico Modelo B-120E/B127A

Tiempo de envío: Retiro en tienda
Precio: $990 / $1990
CARACTERÍSTICAS


# Referencias

[1] https://articulo.mercadolibre.cl/MLC-444519559-feniex-industries-c-1060-haleo-600-6-panel-deinterruptor-_JM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 (https://articulo.mercadolibre.cl/MLC-444519559-feniex-industries-c-1060-haleo-600-6-panel-de-interruptor-_JM)
[2] https://www.tomtop.com/es/pk2874.html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 view (https://www.tomtop.com/es/p-k2874.html?currency=CLP&Warehouse=CN&aid=gplaclcd)
[3] https://www.banggood.com/es/Racing-Car-Combination-Ignition-Switch-Panel-One-Button-Start-LED-for-XH-3018-12V-p-1000286.html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 (https://www.banggood.com/es/Racing-Car-Combination-Ignition-Switch-Panel-One-Button-Start-LED-for-XH-3018-12V-p-1000286.html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)
[4] https://articulo.mercadolibre.cl/MLC-440686963-interruptor-racing-corte-rapido-consulte-porcolores-stock-_JM (https://articulo.mercadolibre.cl/MLC-440686963-interruptor-racing-corte-rapido-consulte-por-colores-stock-_JM)
[5] https://articulo.mercadolibre.cl/MLC-450735324-10pcs-azul-led-interruptor-paraautomovilcamion-_JM (https://articulo.mercadolibre.cl/MLC-450735324-10pcs-azul-led-interruptor-para-automovilcamion-_JM)
[6] https://articulo.mercadolibre.cl/MLC-449942550-interruptor-de-12v-interruptor-de-encendidomotor-reles-int-_JM (https://articulo.mercadolibre.cl/MLC-449942550-interruptor-de-12v-interruptor-de-encendido-motor-reles-int-_JM)
[7] https://articulo.mercadolibre.cl/MLC-448047675-10pcs-azul-luz-led-interruptor-spst-12v-20aonoff-para-_JM (https://articulo.mercadolibre.cl/MLC-448047675-10pcs-azul-luz-led-interruptor-spst-12v-20a-onoff-para-_JM)
[8] https://articulo.mercadolibre.cl/MLC-450957079-interruptor-on-off-con-tapa-y-luz-para-auto-_JM
[9] https://articulo.mercadolibre.cl/MLC-451090766-repuesto-interruptor-para-vehiculo-bipolar-on-offpalanca-_JM (https://articulo.mercadolibre.cl/MLC-451090766-repuesto-interruptor-para-vehiculo-bipolar-on-off-palanca-_JM)
[10] https://articulo.mercadolibre.cl/MLC-451089025-repuesto-interruptor-para-vehiculo-automatico-3-pin-barco-_JM (https://articulo.mercadolibre.cl/MLC-451089025-repuesto-interruptor-para-vehiculo-automatico-3-pin-barco-_JM)
[11] https://articulo.mercadolibre.cl/MLC-447207805-e-support-12v-20a-amp-interruptor-de-palanca-_JM (https://articulo.mercadolibre.cl/MLC-447207805-e-support-12v-20a-amp-interruptor-de-palanca-_JM)
[12] https://articulo.mercadolibre.cl/MLC-448692911-mictuning-12v-24v-aluminio-panel-deinterruptor-impermeab-_JM (https://articulo.mercadolibre.cl/MLC-448692911-mictuning-12v-24v-aluminio-panel-de-interruptor-impermeab-_JM)
[13] https://articulo.mercadolibre.cl/MLC-450217079-interruptor-de-encendido-kdl-panel-dc12v-ledfibra-de-carbo-_JM (https://articulo.mercadolibre.cl/MLC-450217079-interruptor-de-encendido-kdl-panel-dc12v-led-fibra-de-carbo-_JM)

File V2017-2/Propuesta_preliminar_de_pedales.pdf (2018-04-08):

## Avance Equipo Pedales

Pedro Correa y Claudio Yáñez

### Trabajo Realizado

- Identificación de requisitos:
- Acelerador: Entrada al controlador debe variar entre 0 y 5 [V].
- Freno: Interruptor que cierra el circuito de las luces y da señal de freno al computador.


- Cotizaciones:
- Link: https://docs.google.com/spreadsheets/d/1ESKUC-KvJFA4MY9Ess153wOLgx9B4veOIeCC6dQ7AEo/edit?usp=sharing (https://docs.google.com/spreadsheets/d/1ESKUC-KvJFA4MY9Ess153wOLgx9B4veOIeCC6dQ7AEo/edit?usp=sharing)
- Botón pedal de freno: $1870 en adelante. Disponible en 10 de Julio (tienda Multirepuestos y otras). Diferentes modelos tienen diferentes medidas de hilo. Foto:
https://www.dropbox.com/s/vnwlxnkbujzesh5/Bot%C3%B3n%20freno.jpeg?dl=0
- Pedal acelerador:
- http://kellycontroller.com/kelly-5v-accelerator-p-1459.html No dispone de todo el rango (es de 0.86V a 4.2V de acuerdo con lo señalado por ellos en email). Hacen envíos a Chile por Fedex, tardan 5-6 días. $25 USD sin envío.
- http://kellycontroller.com/kelly-5k-throttle-pedal-p-1131.html Recomendado por Kelly Controller (dispone de todo el rango). $79 USD sin envío.
- Múltiples pedales diferentes en desarmadurías de 10 de Julio. En Arturo Prat 736 y 770 tienen pedales desde los $35.000, la mayoría rondan los $70.000. Todos son cajas negras, por lo que probablemente haya que desarmarlos y usar sólo el actuador. Fotos: https://www.dropbox.com/s/hwrwc51d9iijug3/Pedal%20de%20Acelerador.jpeg?dl=0 (https://www.dropbox.com/s/hwrwc51d9iijug3/Pedal%20de%20Acelerador.jpeg?dl=0)

https://www.dropbox.com/s/bj7ixkmq3exyuqh/Zoom%20Modelo%20Pedal.jpeg?dl=0 (https://www.dropbox.com/s/bj7ixkmq3exyuqh/Zoom%20Modelo%20Pedal.jpeg?dl=0)

### Trabajo por Realizar

- Enviar cotizaciones a Rodrigo Chi para poder seleccionar entre las distintas opciones.
- Coordinar con Camila Correa de Plataforma Base para definir los puntos de anclaje que requerirá el pedal del acelerador y el sensor de freno. Primero hay que tener definido el pedal.

### Dudas y Dificultades

- Ninguna por el momento

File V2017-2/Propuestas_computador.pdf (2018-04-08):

Autor: Mauricio Romero Jofré Fecha: 29 de octubre de 2017

Computador

La propuesta de computador del vehículo consiste en una Raspberry Pi. Ésta tiene las siguientes caracteristicas [1], [2]:

- 26 pines digitales de propósito general
- Puerto USB.
- Puerto de audio.
- Puerto HDMI.
- Puerto Ethernet

La alimentación necesaria para la Raspberri es de 5 V con 2 A +o 700 mA (dependiendo del modelo). Se puede alimentar a través de un cable MicroUSB.

Dado el enfoque que ha tenido el desarrollo del proyecto lo principal es utilizar los pines de propósito general para tener comunicación con los sensores y pantalla para mostrar el estado del auto y sensores. Dentro de las posibilidades de programación de la Raspberry para crear el sistema operativo del automóvil está Linux(Raspbian)+Python o Linux(Raspbian)+ROS (Robot Operative System) [3]. En ambas plataformas es posible diseñar los sistemas de control necesarios para el auto.

Uno de los principales problemas entre la comunicación de sensores con la Raspberry es que las entradas y salidas que se pueden realizar con ella son sólo digitales, lo que produce un problema de adaptación con los sensores. Además, dado que los pines libres son limitados, eso produce una restricción respecto al número de sensores a conectar (tanto presentes como futuros). Existen diferentes casos.

Si los sensores son analógicos se deben utilizar ADCs de manera que exista compatibilidad entre los tipos de señales que puede recibir la Raspberry. En el caso de sensores digitales, hay que conocer el protocolo de comunicación que utilicen. Esto puede ser un gran problema, puesto que si se conecta cada sensor a cada pin de la Raspberry, se debe configurar por el lado de la Raspberry que distintos pines sean leidos de manera distinta. Esto puede acarrear un gran desorden si se conectan/desconcetan sensores durante las pruebas. Una forma de combatir la situación es implementar una arquitectura de bus en el automovil, de manera que sensores y actuadores compartan el esquema comunicativo entre si. La complejidad de implementación está en acoplar a cada sensor y actuador electrónica que realice la interfaz entre el dispositivo y el bus. Se pueden utilizar Arduinos Nano como controladores del bus, dado su bajo precio y tamaño. Una virtud del esquema de bus es que se pueden acoplar más sensores que el pinaje da fábrica de la Raspberry.

Diferencial Electrónico

También me dediqué a buscar en la literatura formas de implementación de diferenciales electrónicos. Existen numerosos trabajos en la página de la IEEE, que dan cuenta que es un problema que está en constante desarrollo [4] [5] [6] [7] [8]. Existen modelos complicados, en donde se estiman fuerzas sobre ruedas, relaciones geométricas, distintos ángulos de giro, momento de inercia, etc. Además, en algunas publicaciones se refieren a como estimar parámetros necesarios para calcular posteriormente la velocidad en cada rueda. Otros buscan una implementación rápida del diferencial basada en la programación de FPGAs. Lo principal que se puede concluir es que en [9] determinan una sencilla ecuación para determinar la velocidad de las ruedas de tracción a través de dimensiones del automovil, ángulo de giro del volante y velocidad angular de las ruedas. La piedra angular del modelo es estimar de manera precisa la velocidad angular de las ruedas y el ángulo de giro del volante, por lo que realizar un buen trabajo en la parte del computador se verá reflejado en el desempeño del diferencial.

Por último, se debe pensar en implementar un sistema que identifique cuando se está verdaderamente en una curva y cuando se está resbalando producto de las condiciones del suelo. La falencia de este sistema puede significar poner en riesgo la integridad de los usuarios y mundo alrededor.

Referencias

[1] Raspberrry Pi
https://www.raspberrypi.org/documentation/usage/gpio-plus-and-raspi2/
[2] Raspberri Pi
https://www.raspberrypi.org/documentation/setup/
[3] ROS
http://wiki.ros.org/ROSberryPi/Installing%20ROS%20Kinetic%20on%20the%20Raspberry%20Pi
[4] Y. E. Zhao, J. W. Zhang, X. Q. Guan. Modeling and simulation of electronic differential system for an electric vehicle with two motor-wheel drive.
[5] Xiaodong Wu, Li Yang, Min Xu. Speed following control for differential steering of 4WID electric vehicle.
[6] Yee-Pien Yang, Xian-Yee Xing. Design of electric differential system for an electric vehicle with dual wheel motors.
[7] Xiaodong Wu, Min Xu, Lei Wang. Differential speed steering control for four-wheel independent driving electric vehicle.
[8] Merve Yildirim, Eyyüp Óksüztepe, Burak Tanyeri, Husan Kürüm. Design of electronic differential system for an electric vehicle with in-wheel motor.
[9] Yiming Cui, Yi Shen, Xin Zhang, Yan Wang, Miao Zhang. Electric differential control for electric vehicles based on EMD method.

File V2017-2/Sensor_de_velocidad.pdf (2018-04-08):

EH2203 – Informe

U. de Chile. FCFM. DIE | ~1~

Sensor de Velocidad

Universidad de Chile
Facultad de Ciencias Físicas y Matemáticas Departamento de Humanidades
EL5002 – Introducción al taller de Diseño

## INFORME/ACTA:

## SENSOR DE VELOCIDAD

Nombre Alumno : | Solange Vivanco
Profesor | : | Andrés Caba
Fecha | : | 27 de Octubre del 2017
| | Santiago, Chile.


U. de Chile. FCFM. DIE | ~2~

Sensor de Velocidad

## 1. Sensor de Velocidad

El sensor de velocidad propuesto es un sensor óptimo incremental (Encoder) el cual basa su funcionamiento en dos pares de emisor/receptor compuesto por un LED emisor y un fotorreceptor. Los haces de luz pasan a través de un disco unido al eje de giro, este disco posee marcas opacas con el fin de generar una señal cuadrada en los receptores. Dado que estos pares están desfasados, la señal generada por un par estará adelantada respecto de la otra lo que permitirá determinar el sentido de giro de la rueda y así discriminar si el auto está avanzando o está retrocediendo.

Se están buscando los encoders necesitados y la mejor forma en la cual pueden instalarse. Cabe señalar que todavía no está 100% confirmado que este sensor será el que se utilizará finalmente.

En cuanto a ofertas para la posterior obtención de estos sensores se encontró un encoder con 2 canales que, si bien no se tiene la descripción total del funcionamiento de este, da un acercamiento a la realidad del precio de estos sensores: El precio de uno de estos sensores es $14.000 y dado que se necesitarían 2 dispositivos (uno para cada rueda) se necesitan $28.000.

Los vínculos tanto del funcionamiento del dispositivo propuesto y el encontrado están en la siguiente sección.

Este tema se está investigando en conjunto con Cecilia Ibarra por lo cual, siendo 2 personas, es suficiente para cubrir el tema.

U. de Chile. FCFM. DIE | ~3~

Links

## 2. Links

[1] | http://www.forosdeelectronica.com/f16/encoders-informacion-tecnica-25/INFORME BELMONT:
| Principios éticos y normas para el desarrollo de las investigaciones que involucran a seres humanos.*.
| Revista Médica Herediana. 2013;4(3).
[2] https://prezi.com/tpd3hpidmst6/sensores-de-velocidad-y-movimiento/.
[3] http://www.didacticaselectronicas.com/index.php/sensores/encoders/sensores-de-velocidad-
| encoder-fotointerruptor-tac%C3%B3metro-tacometro-detail

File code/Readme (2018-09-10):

En esta carpeta estoy colocando los códigos en que he avanzado en su documentación, faltan algunos todavía.

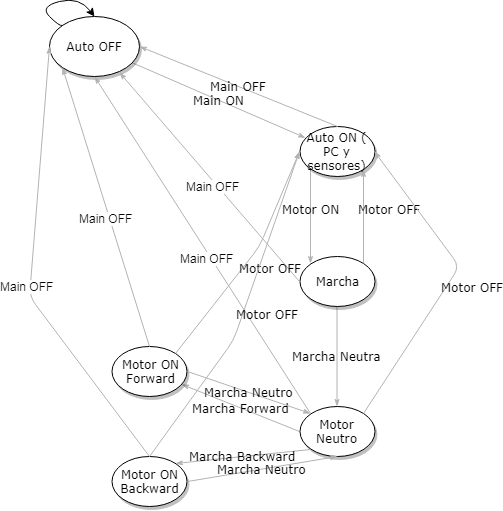
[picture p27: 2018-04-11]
Bibliografia/Comportamiento_Auto_Humano.png

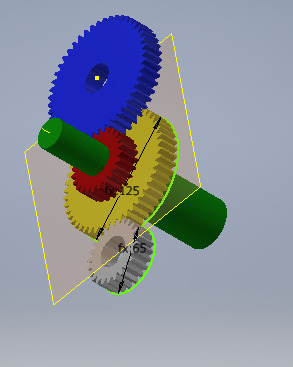
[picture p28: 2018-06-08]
sensor_direccion/engranes_de_lado.jpeg

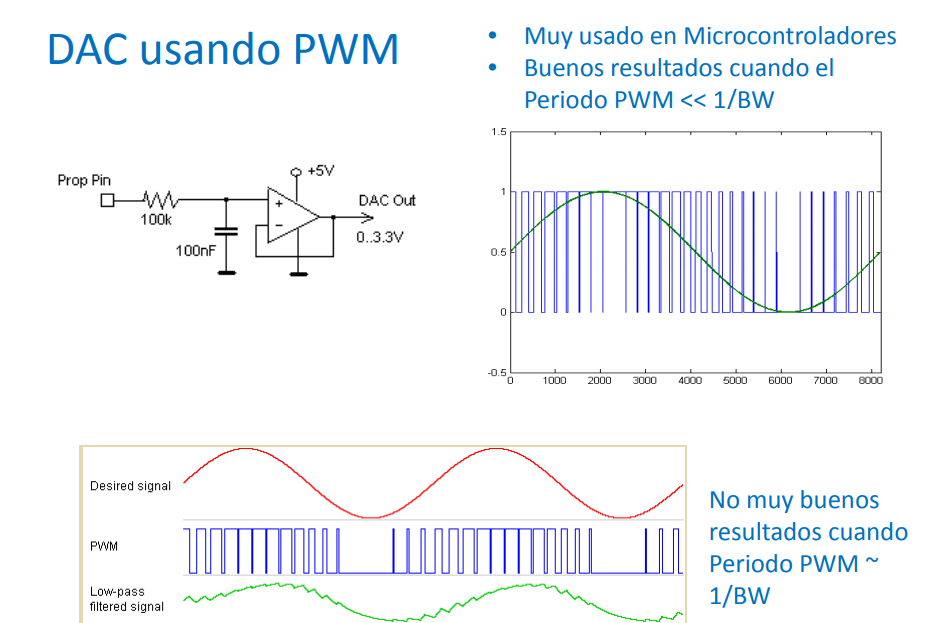
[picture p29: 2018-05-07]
Bibliografia/integrador.png

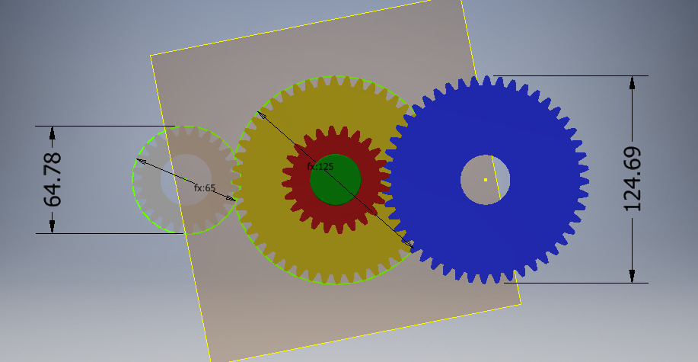
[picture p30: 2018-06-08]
sensor_direccion/engranes_arriba.jpeg

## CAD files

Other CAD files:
sensor_direccion/Spur Gears10.iam
sensor_direccion/Spur Gears12.iam
sensor_direccion/Spur Gears8.iam
sensor_direccion/Spur Gears9.iam
sensor_direccion/assembly_caja.iam
sensor_direccion/base_caja.ipt
sensor_direccion/caja_lateral.ipt
sensor_direccion/cara_posterior.ipt
sensor_direccion/cara_superior.ipt
sensor_direccion/eje_2_3.iam
sensor_direccion/intento3.iam

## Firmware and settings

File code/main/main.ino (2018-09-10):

/* e:
  spimaster

  Created 2018-1
	by Mauricio Romero Jofre, Matías García Gutiérrez

	Este sketch es una prueba del automovil, controlado mediante un arduino UNO.

*/

#include <EngineAdministrator.h>
#include <Engine.h>
#include <Car.h>

// e: PINOUT AUTOMOVIL EN ARDUINO UNO

int pinStF = 22; //status input UNO 13
int pinStN = 23; //status input UNO 12
int pinStB = 24; //status input UNO 11
int pinRET = 2; //right throttle output pwm UNO 5
int pinRES = 26; //right status output digital UNO 4
int pinLET = 3; //left throttle output pwm UNO 6
int pinLES = 27; //left status output digital UNO 7
int pinBrake = 25; // digital UNO 8
int pinAcc = 0; // analog UNO 0

// e: VARIABLES SIN UTILIZAR

int tc = 0; //traction control
float w = 1; //car width
float l = 2; // car length

// e: VARIABLES velo()

float ti = 0;
float tf = millis();
float dt;
float f;

// e: Genera un objeto 'Auto' según la clase Car definida en la librería Car.h

Car Auto(pinAcc, pinBrake, pinStB, pinStN, pinStF, tc, pinRET, pinRES, pinLET, pinLES, w, l);

void setup()
{
/* e:
* Setea la comunicación serial a 9600 baudrate y el pin 2 para interrupciones
* cuando este cambia desde LOW a HIGH.
*/
	attachInterrupt(digitalPinToInterrupt(2), velo, RISING);
	Serial.begin(9600);
}

void loop()
{
/* e:
* Indefinidamente una tras otra vez, lee los sensores y los estados de auto,
* para actuar según lo obtenido como se define en la librería Car.h. Por cada vez,
* imprime en serial en una linea 
* "'Brake'	'Accelación'	'f'	'VelL' \n"
*/
	//EA.startEngines();
  Auto.ReadSensors();
  //Auto.ReadVel(f, 1);
	Auto.ReadState();
	Auto.StateMachine();
  
  Serial.print(Auto.getBrake());
  Serial.print("\t");  
  Serial.print(Auto.getAcc());
  Serial.print("\t");
  Serial.print(f);
  Serial.print("\t");
  Serial.print(Auto.getVelL());
  Serial.print("\t");
  Serial.print(Auto.getState());
  Serial.print("\n");
	//delay(1000);
}

float deg2rad(float angle){
	/* e:
	* Realiza la conversion de angle desde grados a radianes.
	*/
	return angle*3.14/180.;
}

void velo(){
	/* e:
	* Determina el tiempo entre una interrupción y otra, para luego
	* realizar el calculo f = ( (60000 milisegundos * 8)/ (tiempo entre interrupciones) ).
	*/
  tf = millis();
  dt = (tf - ti)*8;
  ti = tf;
  f = 60000/dt;
  
}

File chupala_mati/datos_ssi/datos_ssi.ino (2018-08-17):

int signal_out = 12;
int value = 0;
int counter=0;
int aux=0;
int flag_lectura=0; /*si es high el slave esta leyendo el dato*/
volatile int mask = 512; /*0bx1000000000 */
int save;
void setup() {
  
  Serial.begin(9600);
  pinMode(signal_out, OUTPUT);
  attachInterrupt(0, ssi, RISING ); /*Por defecto clk es high */
  /*attachInterrupt(1, lectura_master, LOW);   /*Esta linea impide q corra normalmente.
   hay que probar con el master, sin ese todo se va a la shit*/ /* si esta leyendo
  el master al slave se resetean los counter y el flag_lectura*/
}


void loop() {
  if (flag_lectura==0){
    /*Serial.print(save, BIN);
    Serial.print("\t");
    Serial.print(counter);
    Serial.print("\t");
    Serial.println(flag_lectura);
    //Serial.println("termino de un envio");*/
    save=0;
    digitalWrite(signal_out, HIGH); /* en ssipor defecto esta en high*/ 
    int pin_pote = analogRead(A0);
    value = pin_pote;
    Serial.println(pin_pote);
  }
  else{
    //Serial.println(save);
     __asm__ __volatile__ ("nop\n\t");
  }  
  
}

void ssi(){
  
  if (counter==9){
    aux = (mask & value);
    //save = save+aux;
    digitalWrite(signal_out, aux);
    counter = 0; // si se alcanza el numero de bits se restea
    flag_lectura = 0;
    mask = 512;
  }
  else{
    aux =  (mask & value);
    aux = aux>>(9-counter);
    //save = save+aux;
    digitalWrite(signal_out, aux);
     /*value = value >> 1; */ /*cuidado puede que ṕase un cero al girarlo :O...
    aunque no debiese pasar nada.*/
    mask = mask >>1;
    counter ++;
    flag_lectura = 1;
    //save = save<<1;  
  }
}

void lectura_master(){
  counter = 0;
  flag_lectura = 0;
}

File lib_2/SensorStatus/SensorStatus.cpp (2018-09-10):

#include "Arduino.h"
#include "SensorStatus.h"
#include <math.h>  //no se si es necesario o si viene con arduino.h ?
/*no se si hay q incluir algo mas aqui...  */


SensorStatus::SensorStatus(int pinclk_dir, int pindata_dir, int nbits_dir, int sincsim_dir)
{
    //setup direccion
    pinMode(pinclk_dir, OUTPUT);
    pinMode(pindata_dir, INPUT);
    pinMode(sincsim_dir, OUTPUT);
    _nbits_dir = nbits_dir;
    _pinclk_dir = pinclk_dir;
    _pindata_dir = pindata_dir;
    _sincsim_dir = sincsim_dir;
    digitalWrite(pinclk_dir, HIGH); //clk de dir por default es high
}
float SensorStatus::get_dir(){
    int val_read = 0;
    int perder_tiempo = 0;
    digitalWrite(_sincsim_dir, HIGH);
    delay(30);
    int value_actual = 0;
    int count = 0;
    while(count <= (2*_nbits_dir-1)){
        if ((1&count)==0){
            perder_tiempo = perder_tiempo <<1;
            digitalWrite(_pinclk_dir, LOW);
            delay(1);
            count++;
            val_read = digitalRead(_pindata_dir);
            perder_tiempo = perder_tiempo + val_read;
        }
        else{
            value_actual = value_actual << 1;
            digitalWrite(_pinclk_dir, HIGH);
            delay(1);
            val_read = digitalRead(_pindata_dir);
            value_actual = value_actual + val_read;
            count ++;
            }
    }
    digitalWrite(_sincsim_dir, LOW);
    float pos_degree = (2*3.1416)/(pow(2,_nbits_dir))*value_actual;
    return pos_degree;
    //return value_actual;
}

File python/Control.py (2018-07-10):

#import serial
from tkinter import *
import matplotlib.pyplot as plt
import matplotlib.animation as animation
from matplotlib import style
from matplotlib.backends.backend_tkagg import FigureCanvasTkAgg
import time
import numpy as np
import pyfirmata

from Motor import *
from Pid import *


def ang2ang(x):
	return 90*(x - 1) + 45


def read(pin, l=100):
	lec = 0
	for i in range(l):
		lec += pin.read()
	return lec/l


def animate(i):
	t1 = time.time() # tiempo de inicio ejecucion
	# lectura arduino
	vel_set = Bvel.get()/100
	ang = Bang.get()
	vel1 = read(A0)
	vel2 = read(A1)
	# lectura gui
	kp = Bkp.get()/100
	kd = Bkd.get()/100
	ki = Bki.get()/100
	kaw = Bkaw.get()/100
	# diferencial
	m_I.set_vel(v=vel_set, ang=ang)
	m_D.set_vel(v=vel_set, ang=ang)

	# pid
	pid.set_kp(kp)
	pid.set_kd(kd)
	pid.set_ki(ki)
	pid.set_kaw(kaw)
	eI = m_I.vel - vel1
	eD = m_D.vel - vel2
	pid.update(eI)
	# set de frecuencias
	f1 = pid.out
	print(f1)
	#print('velset', vel_set, 'vel1', vel1, 'error', vel_set - vel1)
	D5.write(f1)

	
	# guarda elementos para plot
	y1.append(ang)
	y2.append(vel_set)
	y3.append(m_I.get_vel())
	y4.append(m_D.get_vel())	
	y5.append(vel1)
	y6.append(vel2)
	y7.append(eI)
	y8.append(pid.inte*pid.get_ki()) # eD
	xar.append(np.around(t1 - ti, 2))
	n = len(xar)

	if n<N:
		line1.set_data(xar, y1)
		line2.set_data(xar, y2)
		line3.set_data(xar, y3)
		line4.set_data(xar, y4)
		line5.set_data(xar, y5)
		line6.set_data(xar, y6)
		line7.set_data(xar, y7)
		line8.set_data(xar, y8)
		ax1.set_xlim(0, xar[-1])
		ax2.set_xlim(0, xar[-1])
		ax3.set_xlim(0, xar[-1])
		min1 = min(min(y1), min(y2))
		max1 = max(max(y1), max(y2))
		ax1.set_ylim(min1*(1 - 0.1), max1*(1 + 0.1))
	else:
		ynew1 = y1[-N:]
		ynew2 = y2[-N:]
		ynew3 = y3[-N:]
		ynew4 = y4[-N:]
		ynew7 = y7[-N:]
		ynew8 = y8[-N:]
		line1.set_data(xar[-N:], ynew1)
		line2.set_data(xar[-N:], ynew2)
		line3.set_data(xar[-N:], ynew3)
		line4.set_data(xar[-N:], ynew4)
		line5.set_data(xar[-N:], y5[-N:])
		line6.set_data(xar[-N:], y6[-N:])
		line7.set_data(xar[-N:], ynew7[-N:])
		line8.set_data(xar[-N:], ynew8[-N:])
		ax1.set_xlim(xar[-N], xar[-1])
		ax2.set_xlim(xar[-N], xar[-1])
		ax3.set_xlim(xar[-N], xar[-1])
		min1 = min(min(ynew1), min(ynew2))
		max1 = max(max(ynew1), max(ynew2))
		min2 = min(min(ynew7), min(ynew8))
		max2 = max(max(ynew7), max(ynew8))
		ax1.set_ylim(min1*(1 - 0.1), max1*(1 + 0.1))
		ax3.set_ylim(min2*(1 - 0.1), max2*(1 + 0.1))
	t2 = time.time()
	print('lag', t2 - t1)
	return


def _quit():
	# apaga pwm
	D5.write(0)
	D6.write(0)
	root.quit()     # stops mainloop
	root.destroy()  # this is necessary on Windows to prevent Fatal Python Error: PyEval_RestoreThread: NULL tstate
	return


def refresh():
	ax1.clear()
	return


def set_mean():
	return m


#-------------------------------------------
# Arduino
port = '/dev/ttyACM0' # puerto donde esta conectado el arduino (hay que cambiarlo dependiendo del pc)
board = pyfirmata.Arduino(port) # crea objeto como arduino en puerto anterior

it = pyfirmata.util.Iterator(board) # para que el buffer no haga overflow
it.start()

A0 = board.get_pin('a:0:i')
A1 = board.get_pin('a:1:i')
A2 = board.get_pin('a:2:i')
A3 = board.get_pin('a:3:i')
D5 = board.get_pin('d:5:p') # pwm motor 1
D6 = board.get_pin('d:6:p') # pwm motor 2


#-----------------------------------------------------
# Gui
root = Tk()
root.geometry('1366x768+200+100')
root.title('Display Controlador')
#root.state('zoomed')
root.config(background='#fafafa')


#---------------------------------------------------
# Data
xar = []
y1 = []
y2 = []
y3 = []
y4 = []
y5 = []
y6 = []
y7 = []
y8 = []
N = 100
ti = time.time()

#-------------------------------------------------------
# Car configuration
l = 2
w = 1
m_I = MotorIzquierdo(l, w)
m_D = MotorDerecho(l, w)
pid = PID(kp=1, kd=1, ki=1, kaw=10, o_min=0, o_max=1)

#---------------------------------------------------
# Plot
style.use('ggplot')
fig = plt.figure(figsize=(14, 10), dpi=100)

ax1 = fig.add_subplot(3, 1, 1)
ax1.set_ylim(0, 100)
ax1.set_ylabel('ang deg, vel auto')

ax2 = fig.add_subplot(3, 1, 2)
ax2.set_ylim(0, 0.3)
ax2.set_ylabel('vel motores V')


ax3 = fig.add_subplot(3, 1, 3)
ax3.set_ylim(0, 100)
ax3.set_ylabel('error')
ax3.set_xlabel('tiempo s')

line1, = ax1.plot(xar, y1, 'r')
line2, = ax1.plot(xar, y2, 'r')
line3, = ax2.plot(xar, y3, 'r', color='red', label='set', ls='dashed')
line4, = ax2.plot(xar, y4, 'r', color='navy', label='set', ls='dashed')
line5, = ax2.plot(xar, y5, 'r', color='red', label='izq')
line6, = ax2.plot(xar, y6, 'r', color='navy', label='der')
line7, = ax3.plot(xar, y7, 'r', color='green', label='error')
line8, = ax3.plot(xar, y8, 'r', color='brown', label='integral')

ax2.legend()
ax3.legend()


#ser = serial.Serial('com3', 9600)


#---------------------------------------------------------
# Buttons and scale
button = Button(master=root, text='Quit', command=_quit)
button2 = Button(master=root, text='unitario', command=refresh)
Bang = Scale(master=root, from_=-45, to=45, orient=HORIZONTAL, label='angulo')
Bvel = Scale(master=root, from_=0, to=25, orient=HORIZONTAL, label='vel auto')
lim = 1000
Bkp = Scale(master=root, from_=0, to=lim, orient=HORIZONTAL, label='kp')
Bkd = Scale(master=root, from_=0, to=int(lim/2), orient=HORIZONTAL, label='kd')
Bki = Scale(master=root, from_=0, to=int(lim/2), orient=HORIZONTAL, label='ki')
Bkaw = Scale(master=root, from_=0, to=int(lim/2), orient=HORIZONTAL, label='kaw')

#Bang.grid()

button2.pack(side=BOTTOM)
button.pack(side=BOTTOM)
Bang.pack(side=LEFT)
Bvel.pack(side=TOP)
Bkp.pack(side=LEFT)
Bkd.pack(side=LEFT)
Bki.pack(side=LEFT)
Bkaw.pack(side=TOP)




#---------------------------------------------------------------
plotcanvas = FigureCanvasTkAgg(fig, root)
plotcanvas.get_tk_widget().pack()
#plotcanvas.get_tk_widget().grid()
ani = animation.FuncAnimation(fig, animate, interval=1, blit=False)

root.mainloop()

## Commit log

2018-04-28 add pwm
2018-04-29 add pid v1
2018-04-30 modify pid
2018-05-04 Modificado clase Motor para agregar herencia de MotorIzquierdo y MotorDerecho
2018-05-04 cambios en clase motor y actualizacion de control.py"
2018-05-04 motorModificado renombrado a Motor.py con clases
2018-05-04 Agregado metodos get a la clase PID
2018-05-04 modificado control.py para importar pid desde otro archivo
2018-05-07 add controller wiring diagram, integrator circuit and redefine pwm pins
2018-05-10 add new update plot with buttons and scale
2018-05-10 fix indentation in Pid.py
    [Pid.py, control.py, plot5.py]
2018-05-11 add motor set velocity
2018-05-11 fix pid.py and update plot5.py
    [Pid.py, plot5.py]
2018-05-12 add Control.py (updated version of control.py), more buttons and, fix bugs in Pid.py
    [Control.py, Pid.py]
2018-06-08 agrego documentacion sensor direccion
    [Spur Gears10.iam, Spur Gears12.iam, Spur Gears8.iam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]
2018-07-10 add arduino serial com and new control script with serial com
2018-07-18 Motor.h - Motor.cpp
    Primera versión de la clase Motor de la librería de arduino en C++.
2018-07-18 Add files via upload
    Dos objetos.
    1) Engine.cpp: Corresponde al objeto "Motor" que posee velocidades y ejecuta el enlace entre una señal y el motor.
    2) EngineAdministrator.cpp: Es el objeto encargado de el comportamiento de los motores, es decir, ejecutar el diferencial, controlar las marchas y los estados de encendido o apagado de los motores.
2018-08-02 Update Engine.cpp
    Agregado pin de marcha y pin de aceleración
2018-08-06 add arduino main, update motor class
2018-08-14 add spi master
2018-08-14 agrego codigo spi-slave
2018-08-15 add brake and update states
2018-08-15 add future interruptions
2018-08-25 se colocan los scripts de las simulaciones de lecturas del sensor de direccion
2018-08-28 agrego las librerias para leer sensor de direccion simulado
2018-08-29 agrego libreria sensorstatus con direccion simulada funcional :D
2018-08-29 add velocity
2018-08-29 entrego el dato del sensor de direccion en rads
2018-09-06 agrego la lectura de sensor de dir a car.cpp
2018-09-06 main_driver for driver
2018-09-07 tengo la caga :(
2018-09-10 agrego lib_2 donde el car tiene incluido sensor status
